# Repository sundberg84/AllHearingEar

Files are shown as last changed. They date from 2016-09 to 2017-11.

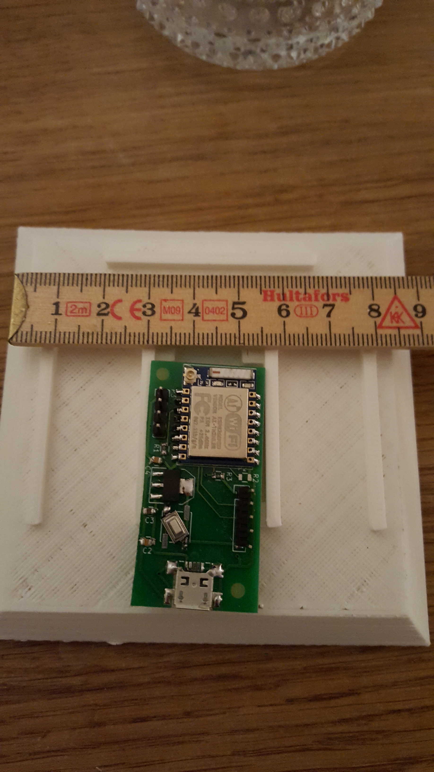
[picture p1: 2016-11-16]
hardware/3d model/Pyramid 0.2/20161116_210414.jpg

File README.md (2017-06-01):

# AllHearingEar
 
## Slogan (eng)
Open the world for your headphones!
Are you afraid of missing out on something with your headphones covering your ears? 

## Produktbeskrivning (eng)
We believe it’s possible to combine a world with your headphones covering your ears and still not miss anything important happening IRL. Are you a gamer with sleeping children or a reader listening to recorded books and are afraid of missing something is happening? We have the product for you - AllHearingEar! Just because you are covering your ears to fully enjoy your sound should not stop you from hearing a crying baby or a visitor ringing the doorbell. 

The AllHearingEar is always and secure connected to you home Wi-Fi and alerts you with the exact recording in real time. This way you can enjoy your gaming, videos, music or voice with headphones in both ears and still safely know you will be alerted if needed.

The AllHearingEar is a onetime, low-cost hardware you connect to your home Wi-Fi. Free apps and software are downloaded and run in the background of your PC, smartphone or tablet. The software and hardware have a live status and will alert you if disconnected. You have the endless possibility to adjust trigger limits from even the smallest sound to a small orchestra.

All this to be able to enjoy your gaming in full 7.1 sound or a quiet book tucked inside a blanket by the fire - and always know you are in control.

## Idé:
Skapa en babymonitor som ansluter till hemmanätverket via WI-FI och bryter aktivt ljud i din hemdator samt spelar upp ljudet som tas upp av mikrofonen i babymonitorn. 
Detta för att kunna underlätta för användaren av datorn när användaren spelar spel, ser film, lyssnar på musik eller liknande.
Idén uppkom när jag och min bror spelade datorspel tillsammans och båda två var tvungna att sitta med endast en hörlur på ena örat.
Vi vill alltså ha möjlighet att höra våra barn om de eventuellt vaknar, utan att tappa ljud när vi arbetar med våra datorer.

##Namn
Om vi nu ska köra på illuminati pyramid kan vi istället för att produkten heter all-seeing-eye heta all-hearing-ear ?

### Utförande
USB-stick
Pyramid

## Ström?

USB Anslutningar - Konsument står för egna adapters.
Anslutes till telefonladdare - standard USB / MicroUSB.

## Hårdvara

Andreas bygger hårdvara i form av kretskort och mikrofoner. Samt designar ett snyggt och praktiskt hölje!

- Esp8266 Wifi Accesspoint/Server (https://github.com/tzapu/WiFiManager )
- 5V VCC (iphone laddare?) Batteri?
- 3.3V för Esp?
- Electret Microphone Amplifier MAX4466
- Statusled?
- Nattlampa LED

"" PreAmplifier
- OPA3344
https://learn.sparkfun.com/tutorials/electret-mic-breakout-board-hookup-guide
http://www.ti.com/lit/ds/symlink/opa345.pdf

Avoid common problems when designing op-amp and in-amp circuits:
http://www.planetanalog.com/document.asp?doc_id=527560

Div PreAmp
https://arduinodiy.wordpress.com/category/audio/

Noice reduction

General power supply and op-amp noise reduction techniques
http://www.diystompboxes.com/smfforum/index.php?topic=74265.0

Basic Concepts of Designing an RF PCB Board:
https://www.eeweb.com/blog/circuit_projects/basic-concepts-of-designing-an-rf-pcb-board

Small- Signal Audio Design (s.541)
https://books.google.se/books?id=pVIdAAAAQBAJ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

http://www.ti.com/lit/an/szza009/szza009.pdf

https://www.maximintegrated.com/en/app-notes/index.mvp/id/5450

## Skal 
3d pyramid
- 3d printad iluminati pyramid (http://www.shapeways.com/product/G3PZPGYJB/illuminati-flat-peice-v2e)
-Hål undertill för väggfäste!

USB sticka:
- https://stickerapp.se/klistermarken/#!
- http://www.mouser.se/ProductDetail/New-Age-Enclosures/P3A-220805S/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

## Länkar Hårdvara

Microfoner: https://store.invensense.com/ProductDetail/ICS43432-InvenSense-Inc/495200/

https://www.hackster.io/middleca/sending-sound-over-the-internet-f097b4

Https://plus.google.com/wm/1/+MarkChaney/posts/EpTNcAjxMak

https://perso.aquilenet.fr/~sven337/english/2016/07/14/DIY-wifi-baby-monitor.html

#### Ljud/Mic till Arduino:

Https://perso.aquilenet.fr/~sven337/english/2016/07/14/DIY-wifi-baby-monitor.html

https://electronpi.wordpress.com/2013/05/28/getting-going-with-an-electret-microphone-and-an-arduino/
Inkl flera länkar på denna sida!

https://www.youtube.com/watch?v=SToBPCajwc0: Mini project: Amplified electret microphone 

Sök arduino electret microphone circuit

## Wishlist
Kamera

## Mjukvara

Marcus utformar en mjukvara till Windows som synkar hårdvaran och bryter eventuellt ljud som spelas upp från datorn. För att sedan spela upp ljudet från monitorn.
Synkning av hårdvara,
 
Volymkontroll för uppspelning av ljud upptaget av mikrofon, 

Volymkontroll för dämpning av ljud aktiva i PC,
 
Volymkontroll för känslighet i mikrofon,
 
Alternativ för autostart av program (Checkbox),
 
Statusinformation, 

Länk till hemsida.

### Länkar till källor.

https://www.nuget.org/packages/NAudio/1.7.3 (NAudio API för inspelning av ljud i VB)

https://social.msdn.microsoft.com/Forums/vstudio/en-US/c9841350-2d83-4863-b491-6d9f75bb1daa/stream-mic-audio-to-another-computer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 (Exempelprogramm för ljudstream via UDP.)

http://www.codeproject.com/Articles/19485/A-Voice-Chat-Application-in-C - A Voice Chat Application in C#

### Wishlist
Knapp för att visa video.
Alternativ för att få video picture in picture när monitor aktiveras.

##Det kommerciella
###Ce/Fee
###Strömadapter
###Förpackning
###Ekonomi
Kickstarter?
###Marknadsföring
Hemsida
Facebook
###Målgrupp
Gamers
Unga med barn
Teknikintresserade (hörlurar) (Sälja hörlurar tillsammans?)
###Användningsområde

Gamers som passar barnen men vill spela
Mammor som lyssnar på ljudböcker? (Kräver app ios/Android?)
Egenföretagare med barn som behöver jobba kväll och vill lyssna på musik.
Studerande med barn som jobbar med datorn och lyssnar på musik.
Musiker som jobbar hemma.
Arbetande tjänstemän som behöver använda en dator i jobbet medans barnen sover.

##Produktbeskrivning/Anvädningsområde
Vi vill alltså ha möjlighet att höra våra barn om de eventuellt vaknar, utan att tappa ljud när vi arbetar med våra datorer.
På ett smart sätt höra din omgivning, exempelvis barn som vaknar, utan att tappa ljud via hörlurarna när man arbetar vid dator/platta/mobil.

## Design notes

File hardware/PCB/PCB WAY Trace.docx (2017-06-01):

PCB WAY 50ohm trace widht

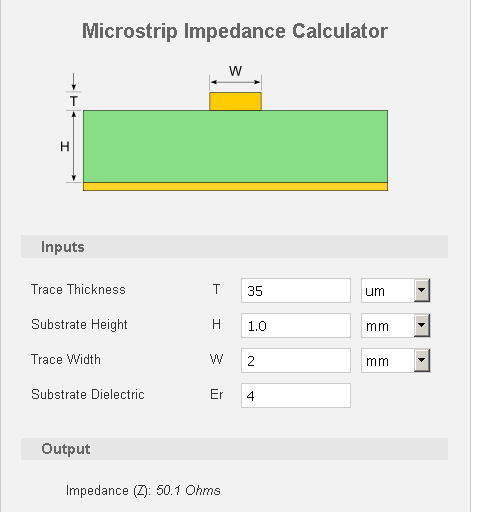
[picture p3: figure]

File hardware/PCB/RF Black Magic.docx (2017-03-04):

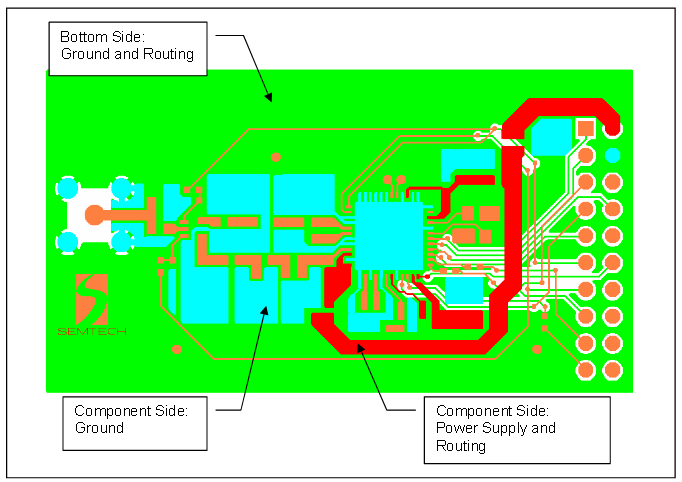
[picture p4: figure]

- power supply trace on the component I s made quite thick so as to present as low as impedance trace as possible.
- Large areas of ground on this side of the board provide a low impedance path for decoupling.
- Wherever possible the bottom (copper) side of the board should allow for a solid ground plane under the RF circuitry.
- the PCB thickness should not exceed 0.8mm - 1.00mm
- Minimize current loops on PCB layouts by decoupling as close to the port being decoupled to ground as possible.
- each circuit block or port has its own decoupling capacitor.
- Ensure that each decoupling capacitor has its own via connection to ground. As a rule of thumb, components should not share vias.

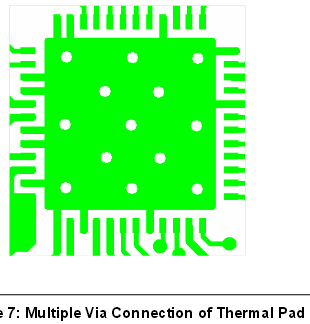
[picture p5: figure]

- Figure 7 illustrates the multiple via (or “well stitched”) connection of the thermal relief pad to the main (inner) ground layer.
- RF Transmission Lines: Lines should be kept as far apart as possible, and should not be routed in close proximity for extended distances.
- High-Speed Digital Signal Lines: These lines should be routed separately on a different layer than the RF signal lines, to prevent coupling. Digital noise (from clocks, PLLs, etc.) can couple onto RF signal lines, and these can be modulated onto RF carriers. Alternatively, in some cases digital noise can be up/down-converted.
- VCC/Power Lines: These should be routed on a dedicated layer. Adequate decoupling/bypass capcitors should be provided at the main VCC distribution node, as well as at VCC branches. The choice of the bypass capacitances must be made based on the overall frequency response of the RF IC, and the expected frequency distribution nature of any digital noise from clocks and PLLs. These lines should also be separated from any RF lines that will transmit large amounts of RF power.
- two layer, the top layer should include the power stage, RF signal lines and RF components. Then the bottom layer must be the ground plane.
- Draw the RF signal lines quite separately. If they are adjacent to eachother, then crosstalk may occur. (Crosstalk : Undesired transfer of signals between or among two lines such as telephone lines, data lines, or system components. )
- When you finish all the layers, fill the empty spaces with copper pour that is connected to the ground. Place vias that are connected to the ground layer with a distance of λ/20 cm between eachother.

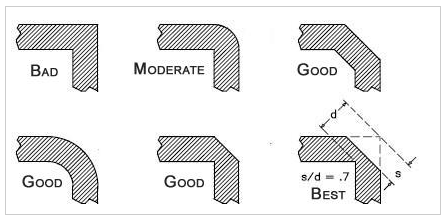
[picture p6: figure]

- Decouple the supply voltage. An example circuit and its PCB is shown below. Consider that the capacitor with a smaller capacitance is placed nearer to the IC.

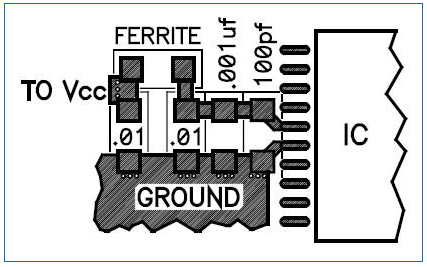
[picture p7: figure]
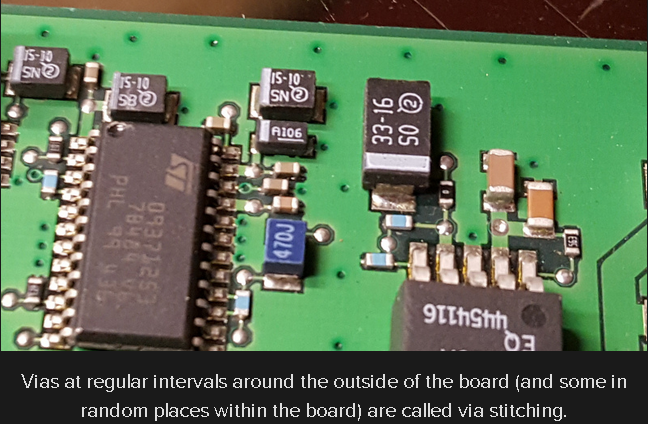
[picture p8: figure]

- trace that is near the edge of the board and farther from a ground plane layer will radiate more electromagnetic interference. Via stitching refers to putting a ring of vias attached to the ground plane all the way around the edge of the PCB (or as much as possible). n addition, a healthy dose of vias should connect the ground pour to the ground plane This prevents accidental antennas, and also ensures that the whole ground stays at the same potential all the time.
- The ferrite bead is usually used when connecting a switching power supply to the power plane, as it isolates the noise from the supply, so it is placed (along with a decoupling capacitor) next to the power supply output.
- Keep Traces Short - The crystal should be as close as possible to the microcontroller, with the wires going directly between the two. Every extra millimeter is more changing electric field and more emissions. A UART can have much longer wires because the signal doesn’t change as fast, and the positive voltage rails can meander all over.
- A two-layer board can achieve 95% of the effectiveness of a four-layer board by emulating what makes a four-layer board better:
  - Make an extra effort to route ground underneath power.
  - Grid power and ground, but be careful not to create unneeded common impedance connections or to violate an intended isolation, such as between high-power and digital grounds. See section 2.2.3, Gridding to Create Planes.
  - Route returns for direct connections to the processor I/Os directly under the signal trace. Gridding is aspace-effective way of doing this. See section 2.2.3, Gridding to Create Planes.
  - Under the microcomputer, build a solid plane for ground that bypassing components and the oscillator loop can be tied to. Tie this ground to the ground pin and the power-supply bypass capacitor. This is called a microcomputerground, which is discussed in section 2.1.3.
- 2.2.3 Gridding to Create Planes

Gridding is the most critical design technique for two-layer boards. Much like a power utility grid, gridding is a network of orthogonal connections between traces carrying ground. It effectively creates a ground plane, which provides the same noise reduction as on four-layer boards. It serves two purposes:

- Emulates the ground plane of a four-layer board by providing a ground return path under each of the signal traces
- Lowers the impedance between the microcomputer and the voltage regulation

Gridding is done by expanding any ground traces and using ground-fill patterns to create a network of connections to ground across the PCB. For example, a PCB has most of the topside traces running vertically and most of the bottom traces running horizontally (see Figure 7). This already is working against having the return run directly under signal. First, every ground trace is expanded to fill up as much of the empty PCB space as possible. Then, all the remaining empty space is filled with ground. Place through holes where top-side traces cross bottom-side traces. Then do the same to the ground-fill patterns. Ground-fill patterns make a better contribution to the grid if they are tied to ground at both ends. A ground-fill-pattern geometry connected at only one point is just a ground shield, but if connected at two or more points, it becomes a conductor, and, therefore, becomes a contributor in the grid.

- Grid as much as possible on a two-layer board. Look for places where small changes in the layout would allow another connection to be made in the grid.
- Use as many through holes as can physically fit.
- Lines do not have to be orthogonal, or of the same width.

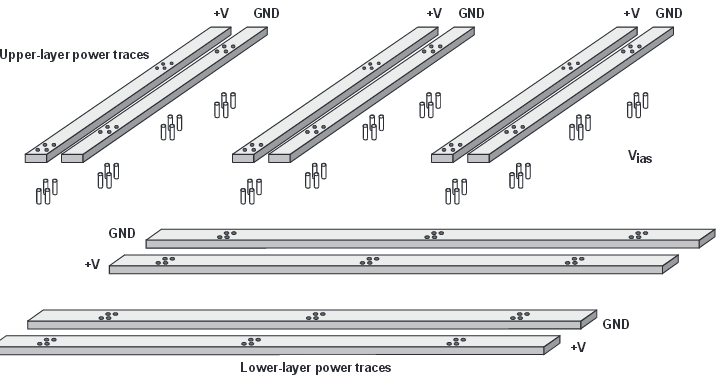
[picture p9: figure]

8

An example of gridding ground only to achieve the effect of a ground plane is shown in Figure 8. Note how the changes made

in order to implement this were minor, indicating how a small effort can have a large payback.

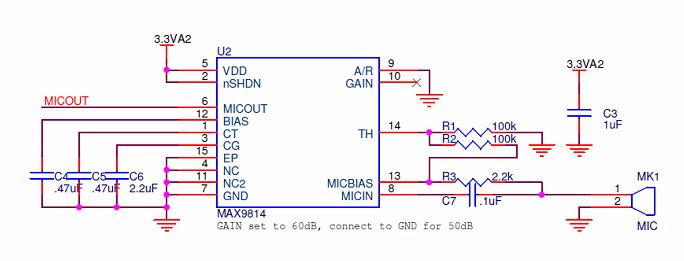
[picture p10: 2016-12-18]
hardware/PCB/UsbSticka/Res/Max9814.JPG

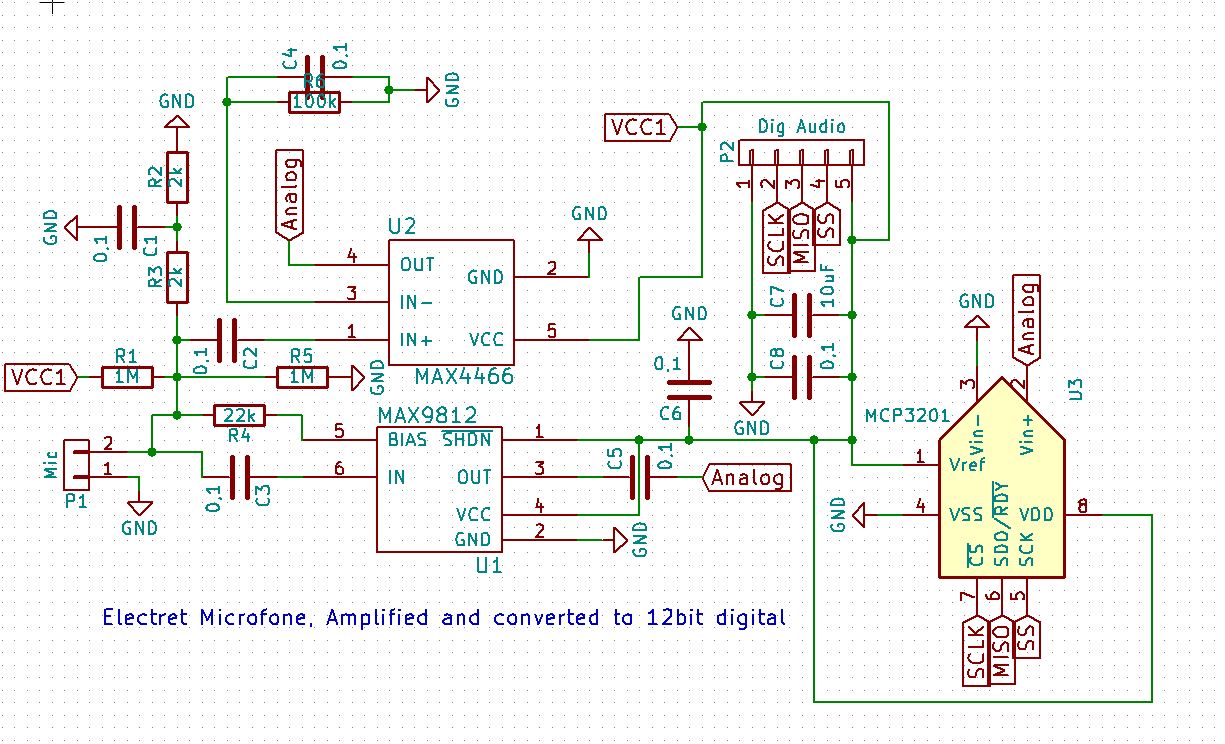
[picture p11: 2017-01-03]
hardware/PCB/UsbSticka/Res/Max4466.JPG

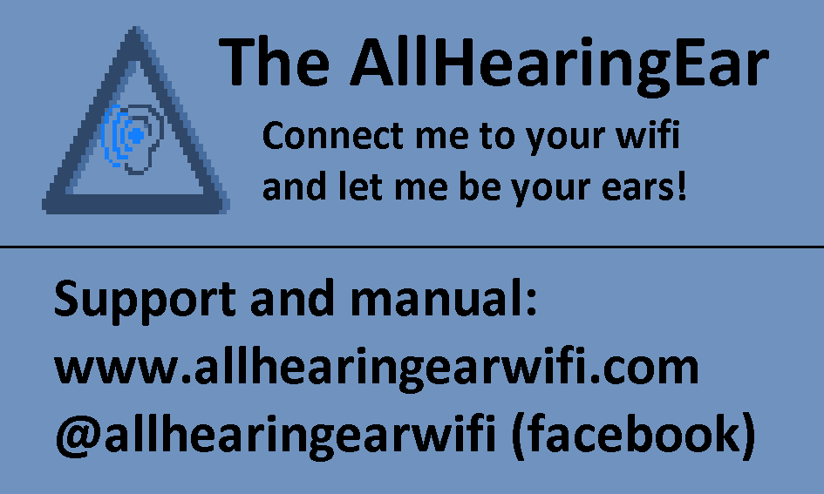
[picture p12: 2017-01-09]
hardware/3d model/sticker.png

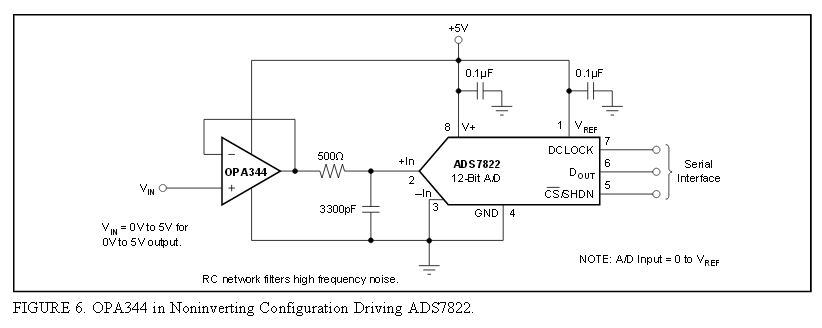
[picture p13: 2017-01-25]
hardware/PCB/UsbSticka/Res/OPA345pADC.JPG

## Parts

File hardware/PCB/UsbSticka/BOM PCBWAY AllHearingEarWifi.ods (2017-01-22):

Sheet: 1
No. | part number/description | Package | Value | Qty | RefDefs | Note
1 | USB Connector |  |  | 1 | P1
2 | LM1117-3.3 | SOT-223 |  | 1 | U1
3 | Capacitors | SMD 0805 | 0.1UF | 6 | C1.C2.C3.C5.C8.C9
4 | Capacitors | SMD 0805 | 10uF | 1 | C4
5 | Resistors | SMD 0805 | 10k | 1
6 | Resistors | SMD 0805 | 2.2k | 2 | R1, R2
7 | Resistors | SMD 0805 |  | 3 | R4.R5.R6
8 | Push Button | SMD |  | 1 | SW1 ??
9 | FERRITE,Capacitors | SMD:C_0805 |  | 1 | FB1
10 | MAX9813 5v | SOT-23-8 |  | 1 | u2
11

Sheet: Sheet1
U2 MT9V022I77ATM_ES@IBGA-52
U1 EMP7032SLC44-15@TQFP12FL12-44
J2 HEADER_13X2@CON26
J1 DOWNCABLE@CON10
X1 OSC@KDS-OSC-2025
C2 CAP_NP@CAP0402
C3 CAP_NP@CAP0402
C8 CAP_NP@CAP0402
C5 CAP_NP@CAP0402
C6 CAP_NP@CAP0402
C7 CAP_NP@CAP0402
C10 CAP_NP@CAP0402
C9 CAP_NP@CAP0402
C11 CAPACITOR_POL@SMC3528
C12 CAPACITOR_POL@SMC3528
L3 INDUCTOR@SMC0603
L2 INDUCTOR@SMC0603
C1 CAP_NP@CAP0402
L1 INDUCTOR@SMC0603
C4 CAP_NP@CAP0402
U3 COMPONENT_1@SOT23-5
C15 1-CAP-POL-MY@SMC3528
C16 1-CAP-POL-MY@SMC3528
R1 R@RES0402
R2 R@RES0402
C13 CAPACITOR_POL@SMC3528
U4 COMPONENT_1@SOT23-5
C19 1-CAP-POL-MY@SMC3528
C20 1-CAP-POL-MY@SMC3528
C14 CAP_NP@CAP0402
C17 CAP_NP@CAP0402
C22 CAP_NP@CAP0402
C18 CAP_NP@CAP0402
C21 CAP_NP@CAP0402
C23 CAP_NP@CAP0402
R3 R@RES0402
R4 R@RES0402

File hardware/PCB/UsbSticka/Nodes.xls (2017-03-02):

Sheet: Overview
ID | Rev | Name | Children | Location | Rep. | Parent | Power | Mys Ver. | Notes
0 | 1.0 | Gateway | Gateway | Hobby | X |  | 5v | 2.0.1b
1 | 1.2 | Hobbyrum | Temp/Hum | Hobby |  |  | Bat | 1.4.1
2 | 1.0 | Stora sovr. | Temp/Hum | Stora sovr. |  |  | Bat | 1.4.1
3 | 1.0 | Vardagsrummet | Temp | Vardagsrum |  |  | Bat | 1.4.1
4 | 1.0 | Radiotestaren | Timeaware | X |  |  | Bat
5 | 1.3? | Utomhus ? | Temp/Hum/Lux/baro | Vedboden | ? | ?/99 | 5V | ?
6
7 | 1.2 | Regn | Rain | Tak garage |  |  | Bat | 2.0b
8 | 1.3 | Elförbrukning | KWH | Proppskåp ute |  |  | Bat | 2.1.0r
9 | 1.2 | Gillestuga temp | Temp | Gillestuga |  |  | Bat | ?
10 | 1.2 | Motion Garage | Motion | Garaget |  | 99 | 5v | 2.0b | Inkl detection led
11 | 1.0 | Motion Vardagsrum | Motion | Vardagsrum |  |  | 5v | ?
12 | 1.3 | Paddington | Motion/Dist | Förräd/Gräskl. |  |  | 5v | 2.0.1b
13 | 1.0 | Utomhus Syd ? | Temp/Hum/Lux | Uterummet |  |  | AC to 5v | 2.0b
14 | 1.0 | UtomhusHumNorr | Temp/Hum | Under trappan |  |  | Bat | 2.0b
15 | 1.0 | UtomhusHumSyd | Temp/Hum | Tak uterum |  |  | Bat | 2.0b
16 | 1.1 | Dec Köket #16 | Motion | Köket |  |  | Bat | 2.1.0r | Slim node 1mhz, APM Optiboot internal 1MHz noBOD 9600baud
17 | 1.0 | Temp Vinden | Temp/hum | Vinden |  |  | Bat | 2.0b
18
19 | 1.2 | UV | UV/Lux | Tak uterum |  |  | Bat | 2.0b
20
99 | 1.2 | WW Sov | Motion | Sov WW | X |  | 5v | 2.1 | Repeater!
100 | 1.6 | Hallen | Repeater | Hallen | X |  | 5v | 2.0.1b | Repeater!
105 | 1.1 | LCD | Switch x 5 (lcd) | Köket | X |  | AC to 5v | 1.6.0b | Down!
106
RFLINK 433mhz
0113C882 |  | 1 | Fönsterlampor Sov
0113C882 |  | 2 | Fönsterlampa WW Sov
0113C882 |  | 3 | Fönsterlampa Malwa Sov
10;NewKaku;1040404;1;OFF |  |  | Taklampa Köket

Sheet: Rev history
ID | Rev | Ver
0 | 1.0
1 | 1.2
2 | 1.0
3 | 1.0
4 | 1.0
5 | 1.0-1.2 |  | Sketch
 | 1.3 |  | Forecast algorithm
 | 1.4 |  | 99 as repeter, 5min sleep eller process hela tiden utan sleep - skicka endast ibland.
6
7 | 1.0 |  | Regn bucket
 | 1.1 | 1.6.0b | Parent=Auto
 | 1.2 | 2.0.0b | Parent Auto, sendHeartbeat()
8 | 1.0 |  | KWH (räknar pulser)
 | 1.1 |  | Bat övervakning + sleep mode igångsatt,
 | 1.2 |  | loop tills count recieved, rensad kod och lagt till ext resistor för debounce.
 | 1.3 | 1.6.0b | Skicka varje 250 pulser
 | 1.4 | 2.1.0r | 2xAA batteri, Sleep time x 5 för rätt sekunders sleep (nu 15 min) (Feb-17)
9 | 1.2
10 | 1.0 |  | Motion med LED på pin 4
 | 1.1 |  | 2.0beta, sänder både 1+0, glömt LED
 | 1.2 | 2.0.0b | LED tillagt igen
11 | 1.0 |  | Motion
12 | 1.0 |  | Motion/Distance
 | 1.1 |  | Tog bort sleep och la till sendHeartBeat() varje timme
 | 1.2 |  | Sänd inga 0 värde (kan ej läsa distance) - fel, ej implement
 | 1.3 | 2.0.1b | Return om distance = 0 för att undvika sändning av falska/error värde (0), ej fixed parent. (Sept 16)
13 | 1.0 |  | Temp/Hum/Lux
14 | 1.0 |  | Temp/Hum
 | 1.1 | 2.1
15 | 1.0 |  | Temp/Hum
16 | 1.0 | 2.0.0b | Motion, 5v motion (9v bat) ingen batövervakning.
 | 1.1 | 2.0.1b | SLim node, 9v to 3.3 via le33az
 | 1.2 | 2.1.0r | Slim node 3.3v 1mhz Optiboot Nu I köket (Feb-17)
17 | 1.0
18
19 | 1.0 | 2.0.0b | UV/Light
 | 1.2 | 2.0.0b | För hög sleep konsumtion, sensors på IO med HIGH/LOW istället.
 | 1.3 | 2.0.1b | BatM() fungerar inte, la till analogReference(INTERNAL); som saknades i setup()
20
21
22
23
24
25
99 | 1.2 | 2.0.1b | Version upgrade, metall folierat case (Sept 16)
 |  | 2.1 | Ny strömadapter, uppdaterad till 2.1
100 | 1.4
 | 1.5 | 2.0.0b | Upgraderar till 1.6.0b, lägger till sänder både 1+0
 | 1.6 | 2.0.1b | Uppgraderar till 2.0.1b, metall case (sept 16)
102 | 1.0 |  | DOWN
103 | 1.0
104 | 1.0
105 | 1.1
106

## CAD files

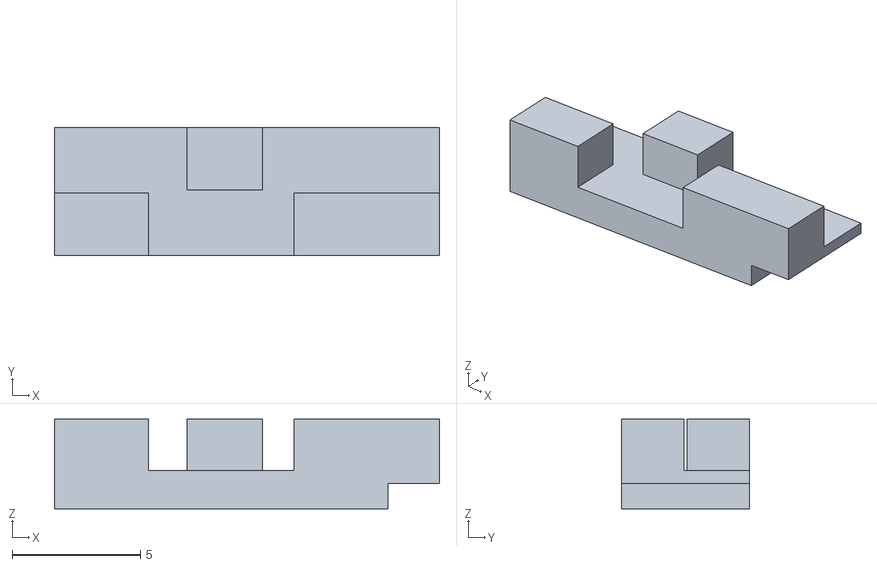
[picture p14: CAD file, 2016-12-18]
hardware/3d model/Bandlås/bandlås-013Bsträng.stl
15.0 x 5.00 x 3.50

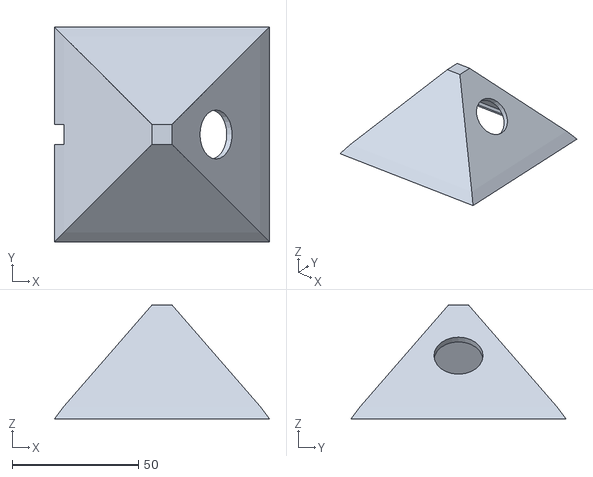
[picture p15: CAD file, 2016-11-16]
hardware/3d model/Pyramid 0.2/Topp02rep.stl
85.0 x 85.0 x 45.0

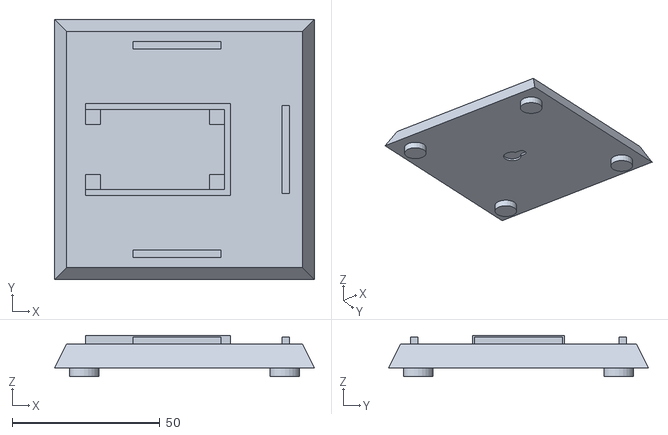
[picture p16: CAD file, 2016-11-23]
hardware/3d model/Pyramid 0.4/PyramidBr.stl
88.0 x 88.0 x 14.0

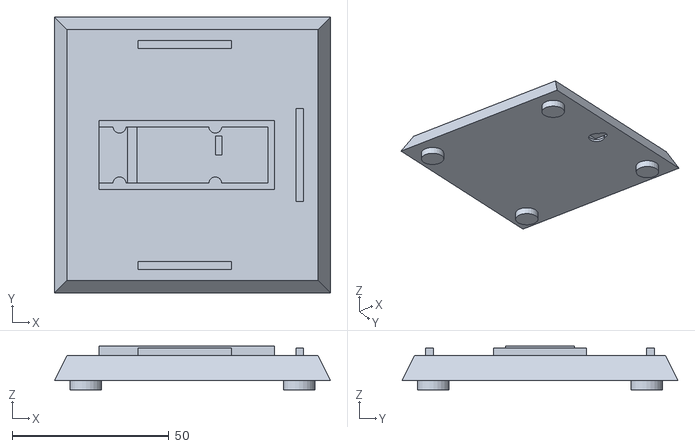
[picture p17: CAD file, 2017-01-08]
hardware/3d model/Pyramid 0.5/BOTT06BUILD.stl
88.0 x 88.0 x 14.0

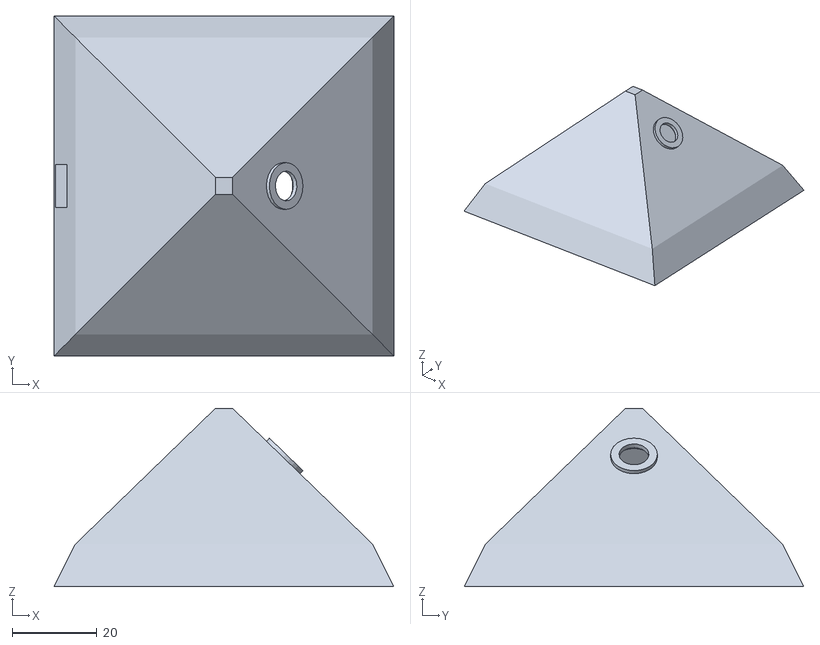
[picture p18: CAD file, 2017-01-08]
hardware/3d model/Pyramid 0.6/TOP06BUILDrep.stl
80.0 x 80.0 x 42.0

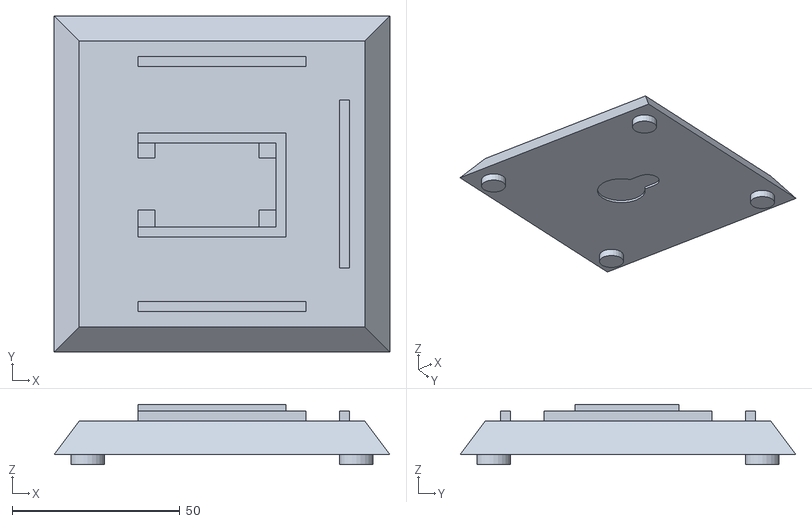
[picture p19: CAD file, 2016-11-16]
hardware/3d model/Pyramid 0.2/Botten02.stl
100.0 x 100.0 x 18.0

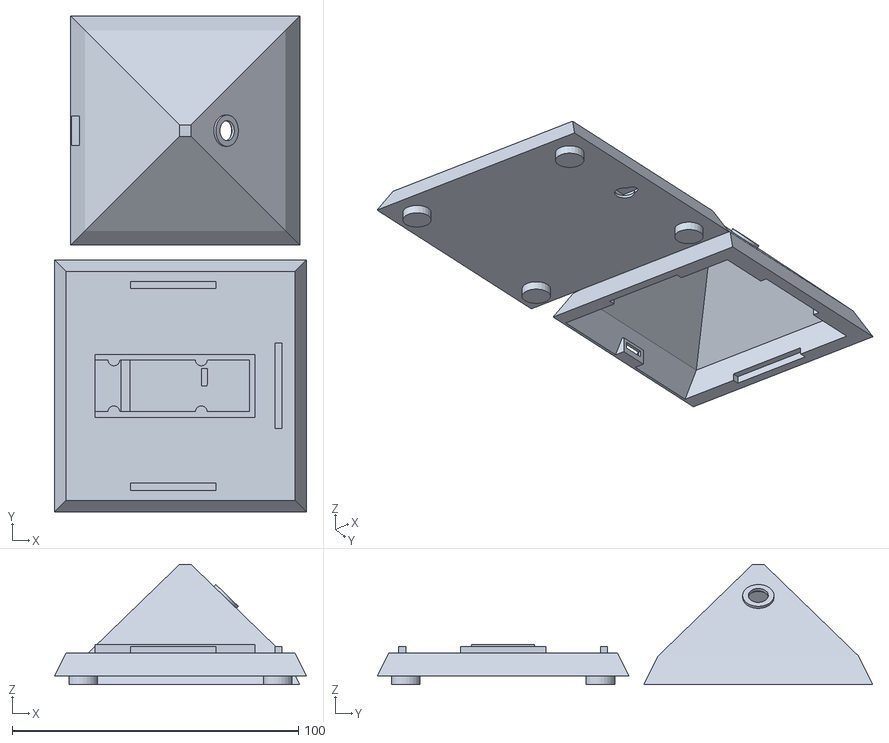
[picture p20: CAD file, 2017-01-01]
hardware/3d model/Pyramid 0.5/Pyramid 0.6BUILDrep.stl
88.0 x 173.1 x 42.0

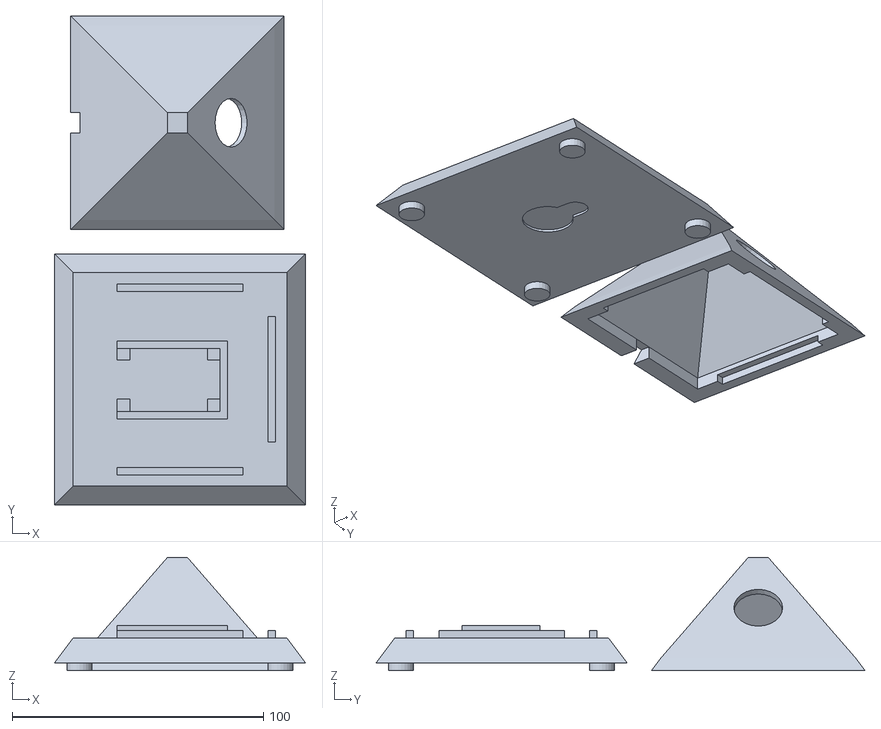
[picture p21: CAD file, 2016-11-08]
hardware/3d model/Pyramid 0.2/Pyramid02.stl
100.0 x 194.7 x 45.0

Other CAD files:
hardware/3d model/Bandlås/bandlås-013Bsträng-rep.stl
hardware/3d model/Pyramid 0.2/Topp02.stl
hardware/3d model/Pyramid 0.4/PyramidTr.stl
hardware/3d model/Pyramid 0.5/TOP06BUILD.stl
hardware/3d model/Pyramid 0.6/newTOP06BUILDrep.stl
hardware/3d model/Pyramid 0.4/PyramidB.stl
hardware/3d model/Pyramid 0.6/BOTT06BUILDrep.stl
hardware/3d model/Pyramid 0.2/Botten02Rep.stl
hardware/3d model/Pyramid 0.4/PyramidT.stl
hardware/3d model/Pyramid 0.5/Pyramid 0.6BUILD.stl
hardware/3d model/Bandlås/bandlås.skp
hardware/3d model/Pyramid 0.1/Pyramid.skp
hardware/3d model/Pyramid 0.1/kretskort.skp
hardware/3d model/Pyramid 0.2/Botten02.skp
hardware/3d model/Pyramid 0.2/Pyramid02.skp
hardware/3d model/Pyramid 0.2/Pyramid02rep.stl
hardware/3d model/Pyramid 0.2/Topp02.skp
hardware/3d model/Pyramid 0.3/Pyramid03.skp
hardware/3d model/Pyramid 0.4/Pyramid 0.4.1.skp
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

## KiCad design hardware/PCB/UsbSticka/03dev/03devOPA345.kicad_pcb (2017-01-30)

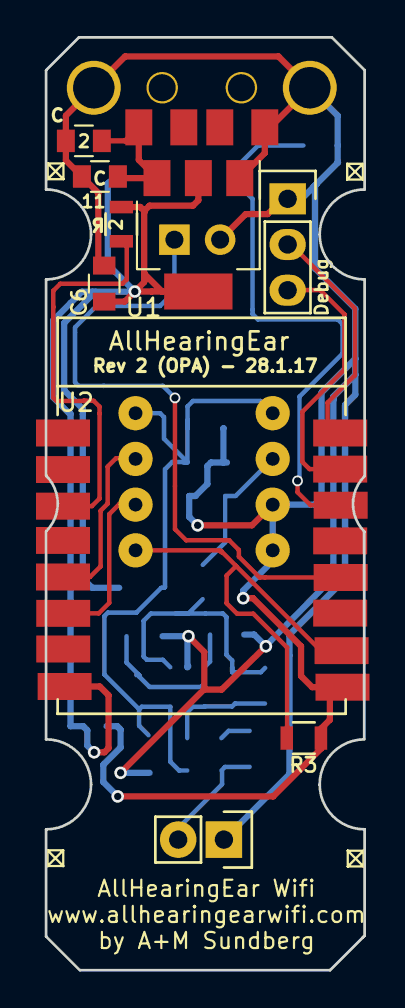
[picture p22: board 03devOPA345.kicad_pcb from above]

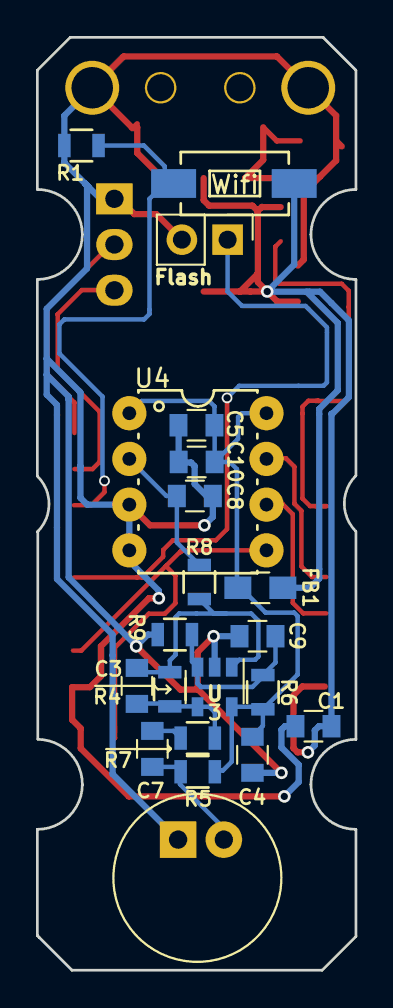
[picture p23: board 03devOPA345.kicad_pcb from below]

Board: 2 copper layers, 17.7 x 51.8 mm, 28 parts (19 on the bottom side), 17 nets.

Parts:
2: 10uF; C_0805
2#2: 10k; R_0805
3: OPA345; SOT-23-5
11: 0,1uF; C_0805
C1, C6: 0,1uF; C_0805
C3, C4, C5, C10: 0,1; C_0805
C7, C9: 4,7; C_0805
C8: 3300pF; C_0805
Debug: Debug; Socket_Strip_Straight_1x03
FB1: FERRITE; C_0805_HandSoldering
P1: USB_B; USB_A_AS_PADS
R1, R3, R6, R7, R9: 10k; R_0805
R4: 820k; R_0805
R5: 2,2k; R_0805
R8: 500; R_0805
U1: LM1117-3.3; SOT-223
U2: ESP-07v2; ESP-07_AS
U4: MCP3201; PDIP-8
Wifi: SW_PUSH; SW_SPST_EVQPE1

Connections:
+5V: 2.1, 11.1, P1.1, U1.3
GND: 2.2, 3.2, 11.2, C1.2, C4.2, C5.1, C6.2, C8.2, C9.1, C10.1, Debug.1, P1.4, P1.5, R1.1, R3.2, R9.2, U1.1, U2.9, U4.3, U4.4
MISO: U2.6, U4.6
unnamed: 3.1, C3.1, R4.1, R8.2
unnamed: 3.4, C3.2, R4.2, R7.1
unnamed: C7.1, R5.1
unnamed: C7.2, R7.2
unnamed: C8.1, R8.1, U4.2
unnamed: 3.3, C9.2, R6.2, R9.1
unnamed: 3.5, C4.1, C5.2, C10.2, FB1.1, R5.2, R6.1, U4.1, U4.8
unnamed: Debug.2, U2.16
unnamed: Debug.3, U2.15
unnamed: R1.2, U2.14, Wifi.1
unnamed: 2#2.1, U2.3
SCLK: U2.5, U4.7
SS: R3.1, U2.10, U4.5
VCC: 2#2.2, C1.1, C6.1, FB1.2, U1.2, U1.4, U2.8, Wifi.2

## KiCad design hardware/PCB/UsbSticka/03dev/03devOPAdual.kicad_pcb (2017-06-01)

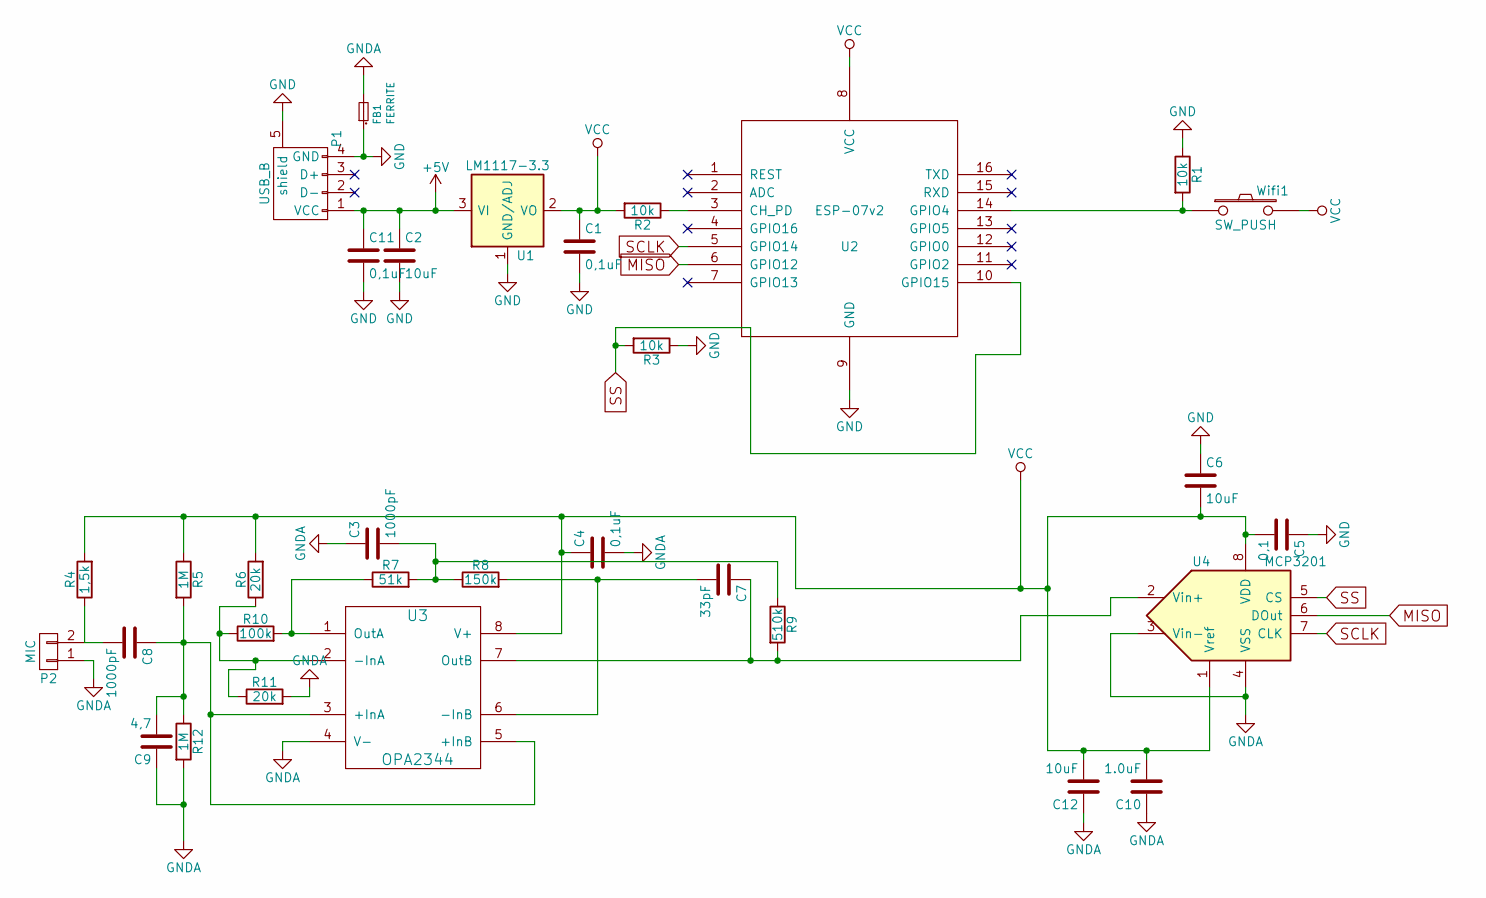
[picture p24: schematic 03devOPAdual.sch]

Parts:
C1, C4, C11: 0,1uF; C_0805_HandSoldering
C2, C6, C12: 10uF; C_0805_HandSoldering
C3, C8: 1000pF; C_0805_HandSoldering
C5: 0,1; C_0805_HandSoldering
C7: 33pF; C_0805_HandSoldering
C9: 4,7; C_0805_HandSoldering
C10: 1.0uF; C_0805_HandSoldering
FB1: FERRITE; C_0805_HandSoldering
P1: USB_B; USB_A_AS
P2: MIC; Socket_Strip_Straight_1x02_Pitch2.54mm
R1, R2, R3: 10k; R_0805_HandSoldering
R4: 1,5k; R_0805_HandSoldering
R5, R12: 1M; R_0805_HandSoldering
R6, R11: 20k; R_0805_HandSoldering
R7: 51k; R_0805_HandSoldering
R8: 150k; R_0805_HandSoldering
R9: 510k; R_0805_HandSoldering
R10: 100k; R_0805_HandSoldering
U1: LM1117-3.3; SOT-223
U2: ESP-07v2; ESP-07_AS
U3: OPA2344; SOIC-8_3.9x4.9mm_Pitch1.27mm
U4: MCP3201; SOIC-8_3.9x4.9mm_Pitch1.27mm
Wifi1: SW_PUSH; SW_PUSH_AS

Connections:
+5V: C2.1, C11.1, P1.1 (VCC), U1.3 (VI)
GND: C1.2, C2.2, C5.1, C6.1, C11.2, FB1.1, P1.4 (GND), P1.5 (shield), R1.1, R3.1, U1.1 (GND/ADJ), U2.9 (GND)
GNDA: C3.1, C4.2, C9.1, C10.1, C12.1, FB1.2, P2.1, R11.2, R12.2, U3.4 (V-), U4.3 (Vin-), U4.4 (VSS)
MISO: U2.6 (GPIO12), U4.6 (DOut)
unnamed: C3.2, R7.2, R8.1, R9.1
unnamed: C7.1, R9.2, U3.7 (OutB), U4.2 (Vin+)
unnamed: C7.2, R8.2, U3.6 (-InB)
unnamed: C8.1, C9.2, R5.2, R12.1, U3.3 (+InA), U3.5 (+InB)
unnamed: C8.2, P2.2, R4.1
unnamed: R1.2, U2.14 (GPIO4), Wifi1.1
unnamed: R2.1, U2.3 (CH_PD)
unnamed: R6.1, R10.1, R11.1, U3.2 (-InA)
unnamed: R7.1, R10.2, U3.1 (OutA)
SCLK: U2.5 (GPIO14), U4.7 (CLK)
SS: R3.2, U2.10 (GPIO15), U4.5 (CS)
VCC: C1.1, C4.1, C5.2, C6.2, C10.2, C12.2, R2.2, R4.2, R5.1, R6.2, U1.2 (VO), U1.4 (VO), U2.8 (VCC), U3.8 (V+), U4.1 (Vref), U4.8 (VDD), Wifi1.2

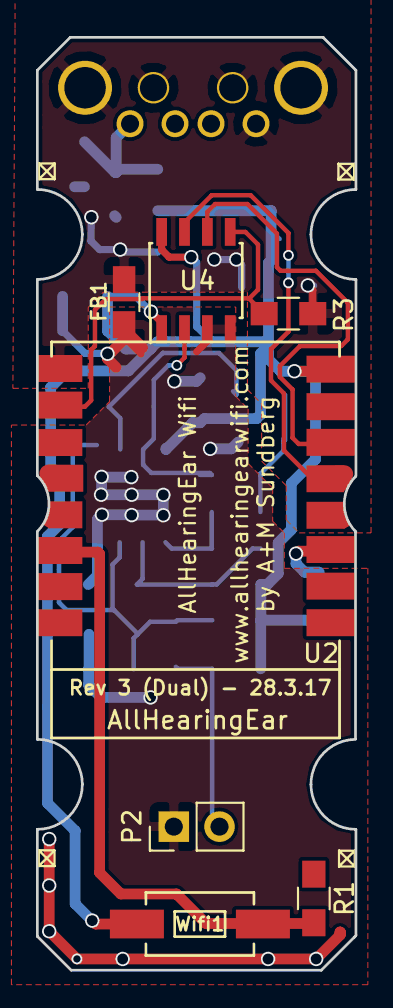
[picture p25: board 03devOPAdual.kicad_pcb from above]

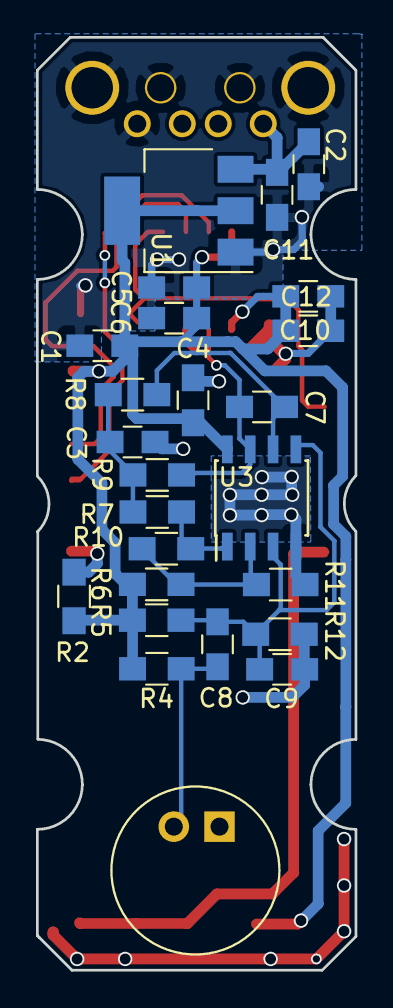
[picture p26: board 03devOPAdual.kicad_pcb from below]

Board: 2 copper layers, 17.7 x 51.8 mm, 32 parts (24 on the bottom side), 16 nets.

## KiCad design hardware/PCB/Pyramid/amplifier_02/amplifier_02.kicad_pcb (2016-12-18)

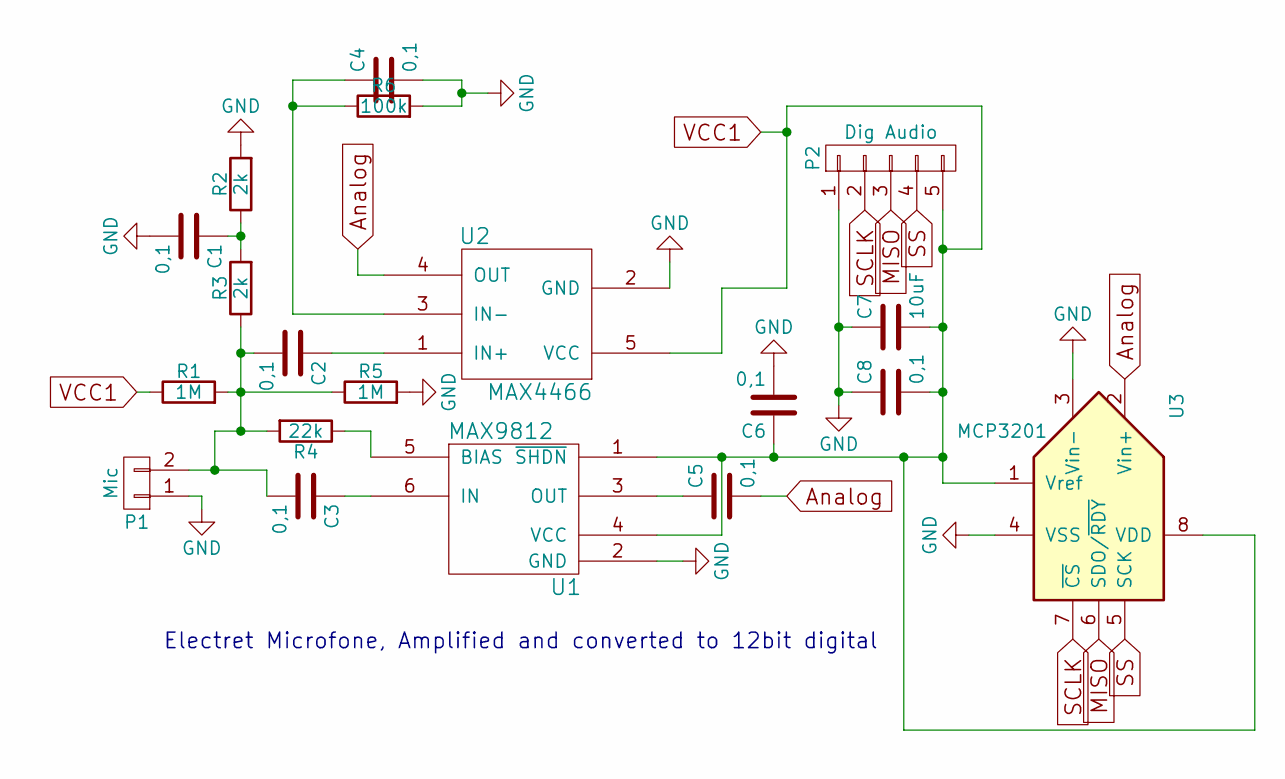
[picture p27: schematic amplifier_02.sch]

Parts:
C1, C2, C3, C4, C5, C6, C8: 0,1; C_0805
C7: 10uF; C_0805
P1: Mic; Pin_Header_Straight_1x02
P2: Dig Audio; Pin_Header_Straight_1x05
R1, R5: 1M; R_0805
R2, R3: 2k; R_0805
R4: 22k; R_0805
R6: 100k; R_0805
U1: MAX9812; SC-70-6
U2: MAX4466; SC-70-5
U3: MCP3201; PDIP-8

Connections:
Analog: C5.2, U2.4 (OUT), U3.2 (Vin+)
GND: C1.2, C4.2, C6.2, C7.1, C8.1, P1.1, P2.1, R2.2, R5.2, R6.2, U1.2 (GND), U2.2 (GND), U3.3 (Vin-), U3.4 (VSS)
MISO: P2.3, U3.6 (SDO/~RDY~)
unnamed: C1.1, R2.1, R3.2
unnamed: C2.1, U2.1 (IN+)
unnamed: C2.2, C3.2, P1.2, R1.2, R3.1, R4.2, R5.1
unnamed: C3.1, U1.6 (IN)
unnamed: C4.1, R6.1, U2.3 (IN-)
unnamed: C5.1, U1.3 (OUT)
unnamed: R4.1, U1.5 (BIAS)
SCLK: P2.2, U3.7 (~CS~)
SS: P2.4, U3.5 (SCK)
VCC1: C6.1, C7.2, C8.2, P2.5, R1.1, U1.1 (~SHDN), U1.4 (VCC), U2.5 (VCC), U3.1 (Vref), U3.8 (VDD)

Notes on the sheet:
Electret Microfone, Amplified and converted to 12bit digital

Board: 2 copper layers, 19 parts (0 on the bottom side), 13 nets, no tracks yet.

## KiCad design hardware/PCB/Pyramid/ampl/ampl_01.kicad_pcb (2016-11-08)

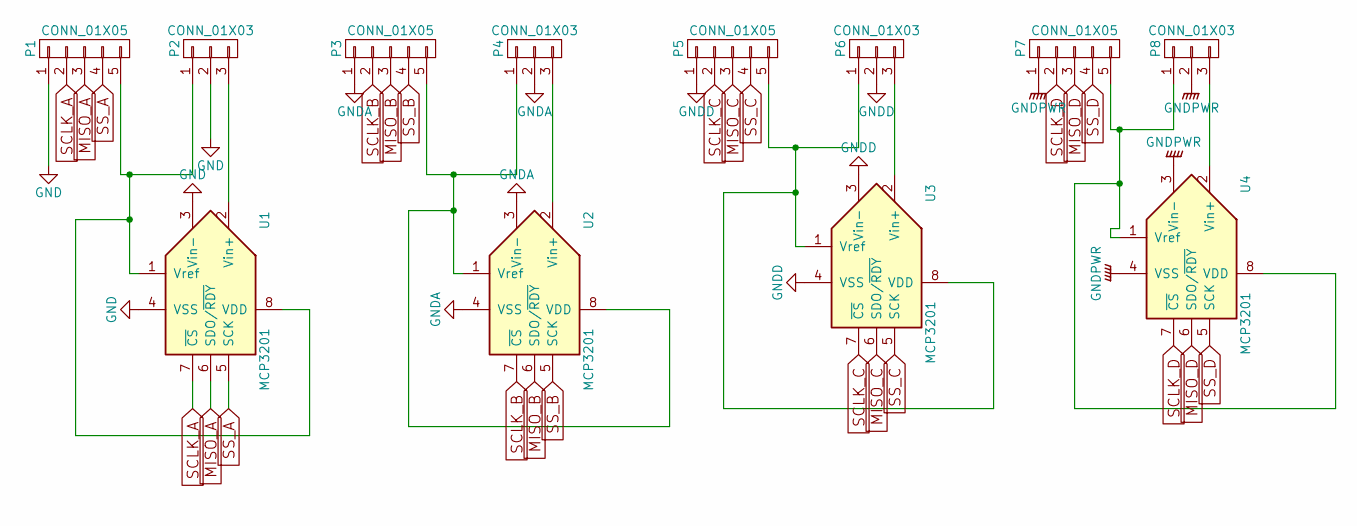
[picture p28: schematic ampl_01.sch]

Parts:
P1, P3, P5, P7: CONN_01X05; Pin_Header_Straight_1x05
P2, P4, P6, P8: CONN_01X03; Pin_Header_Straight_1x03
U1, U2: MCP3201; SOIC-8_3.9x4.9mm_Pitch1.27mm
U3, U4: MCP3201; PDIP-8

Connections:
GND: P1.1, P2.2, U1.3 (Vin-), U1.4 (VSS)
GNDA: P3.1, P4.2, U2.3 (Vin-), U2.4 (VSS)
GNDD: P5.1, P6.2, U3.3 (Vin-), U3.4 (VSS)
GNDPWR: P7.1, P8.2, U4.3 (Vin-), U4.4 (VSS)
MISO_A: P1.3, U1.6 (SDO/~RDY~)
MISO_B: P3.3, U2.6 (SDO/~RDY~)
MISO_C: P5.3, U3.6 (SDO/~RDY~)
MISO_D: P7.3, U4.6 (SDO/~RDY~)
unnamed: P1.5, P2.1, U1.1 (Vref), U1.8 (VDD)
unnamed: P2.3, U1.2 (Vin+)
unnamed: P3.5, P4.1, U2.1 (Vref), U2.8 (VDD)
unnamed: P4.3, U2.2 (Vin+)
unnamed: P5.5, P6.1, U3.1 (Vref), U3.8 (VDD)
unnamed: P6.3, U3.2 (Vin+)
unnamed: P7.5, P8.1, U4.1 (Vref), U4.8 (VDD)
unnamed: P8.3, U4.2 (Vin+)
SCLK_A: P1.2, U1.7 (~CS~)
SCLK_B: P3.2, U2.7 (~CS~)
SCLK_C: P5.2, U3.7 (~CS~)
SCLK_D: P7.2, U4.7 (~CS~)
SS_A: P1.4, U1.5 (SCK)
SS_B: P3.4, U2.5 (SCK)
SS_C: P5.4, U3.5 (SCK)
SS_D: P7.4, U4.5 (SCK)

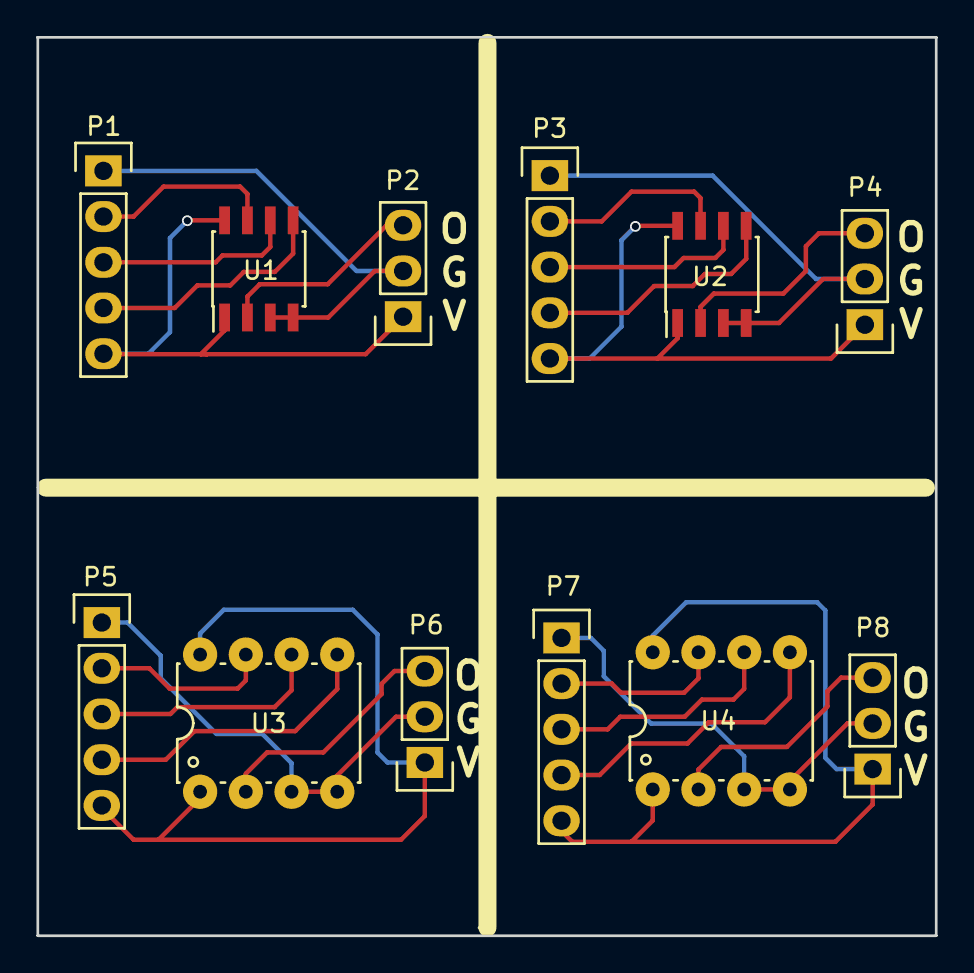
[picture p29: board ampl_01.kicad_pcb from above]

Board: 2 copper layers, 49.9 x 49.9 mm, 12 parts (0 on the bottom side), 24 nets.

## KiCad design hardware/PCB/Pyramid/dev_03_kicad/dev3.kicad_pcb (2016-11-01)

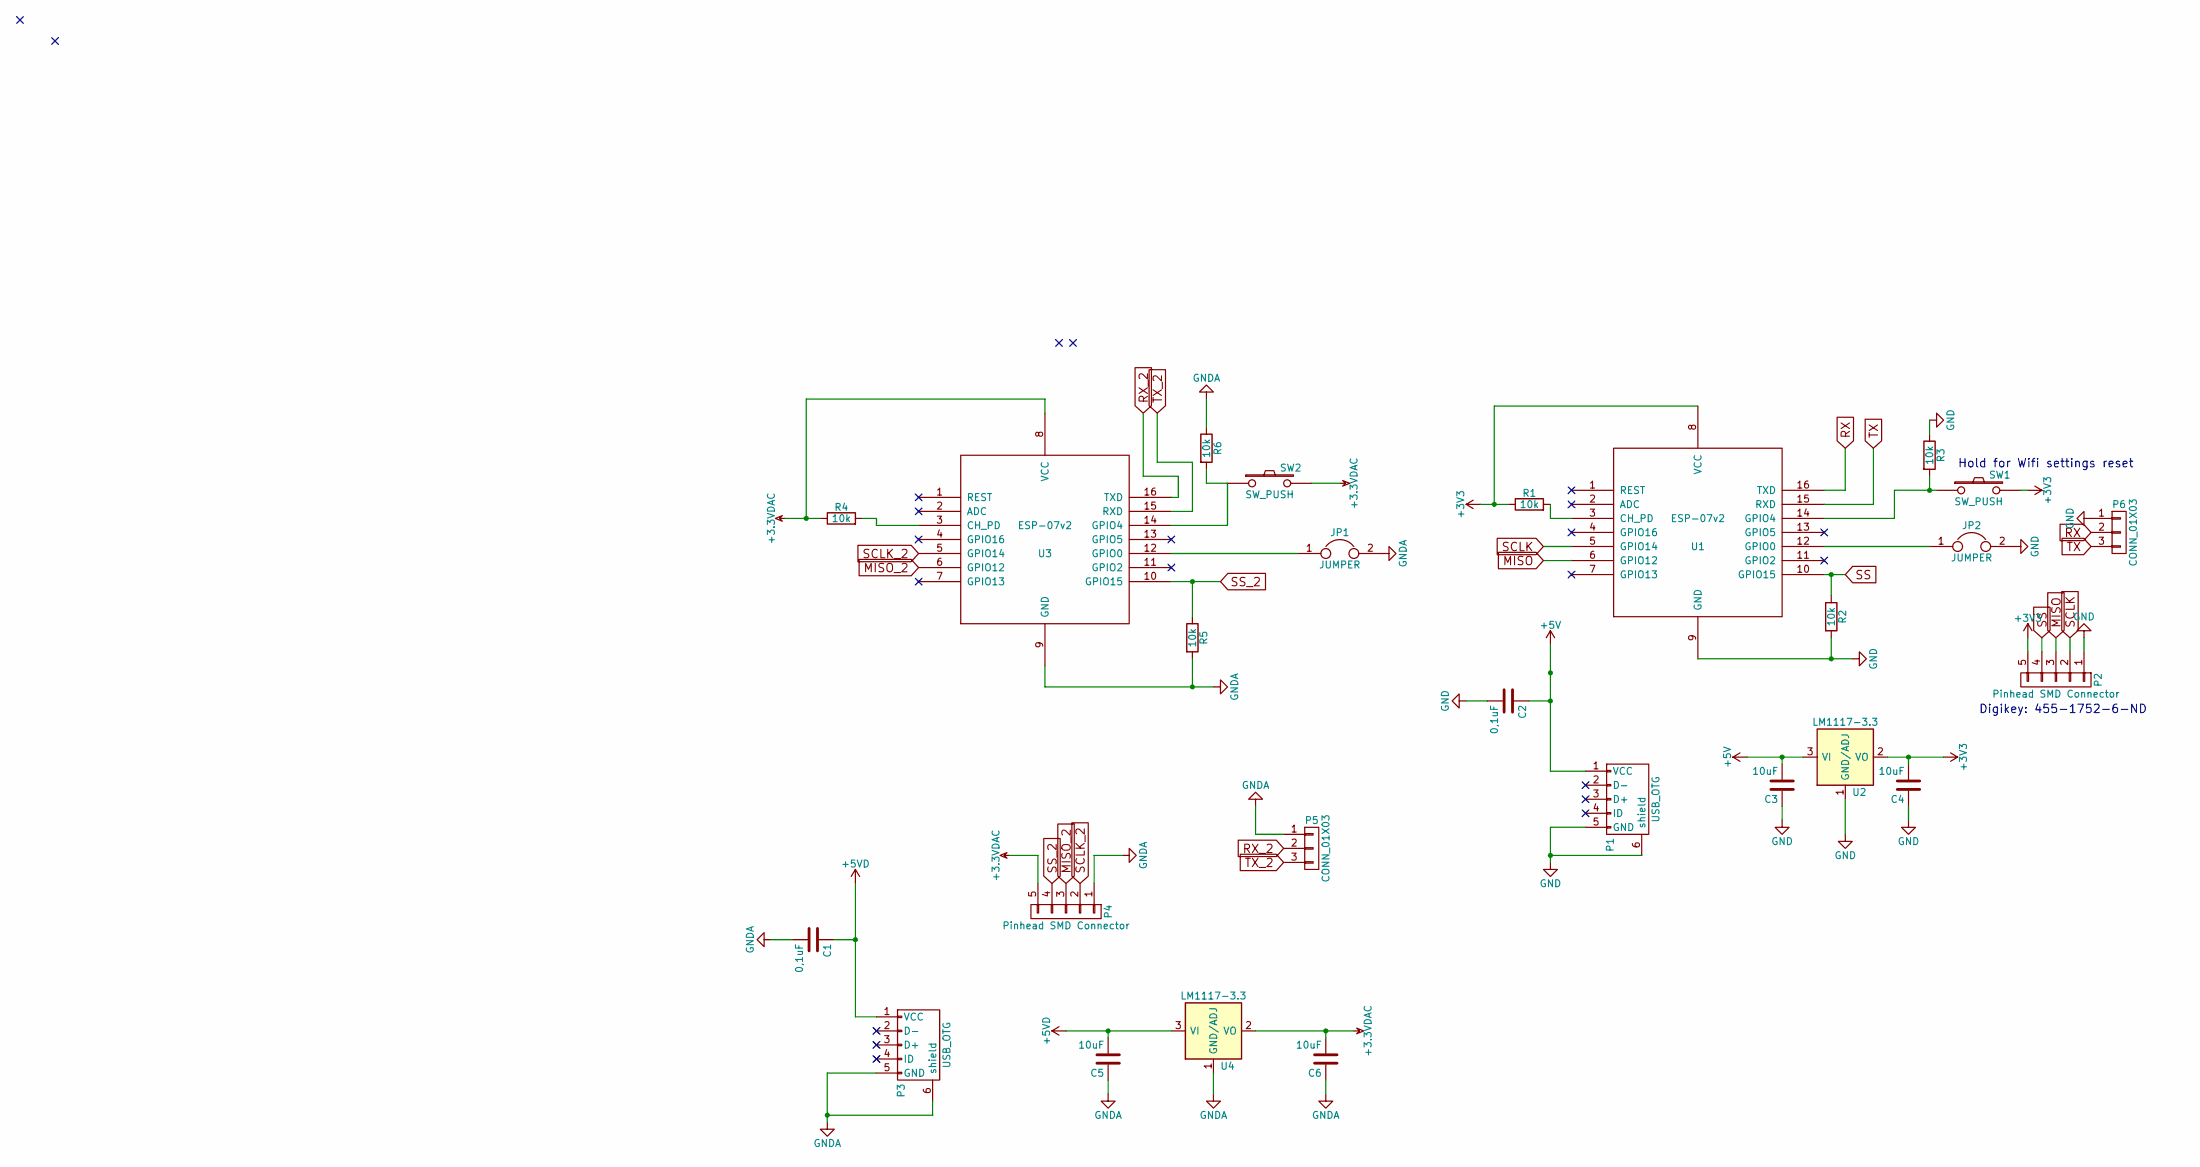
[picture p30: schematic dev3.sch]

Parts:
C1, C2: 0,1uF; C_0805
C3, C4, C5, C6: 10uF; C_0805
JP1, JP2: JUMPER; Pin_Header_Straight_1x02
P1, P3: USB_OTG; USB_Mini-B_AS
P2, P4: Pinhead SMD Connector; Pin_Header_Straight_1x05
P5, P6: CONN_01X03; Socket_Strip_Straight_1x03
R1, R2, R3, R4, R5, R6: 10k; R_0805
SW1, SW2: SW_PUSH; SW_SPST_EVPBF
U1, U3: ESP-07v2
U2, U4: LM1117-3.3; SOT-223

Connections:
+3.3VDAC: C6.2, P4.5, R4.1, SW2.2, U3.8 (VCC), U4.2 (VO), U4.4 (VO)
+3V3: C4.2, P2.5, R1.1, SW1.2, U1.8 (VCC), U2.2 (VO), U2.4 (VO)
+5V: C2.1, C3.2, P1.1 (VCC), U2.3 (VI)
+5VD: C1.1, C5.2, P3.1 (VCC), U4.3 (VI)
GND: C2.2, C3.1, C4.1, JP2.2, P1.5 (GND), P1.6 (shield), P2.1, P6.1, R2.2, R3.1, U1.9 (GND), U2.1 (GND/ADJ)
GNDA: C1.2, C5.1, C6.1, JP1.2, P3.5 (GND), P3.6 (shield), P4.1, P5.1, R5.2, R6.1, U3.9 (GND), U4.1 (GND/ADJ)
MISO: P2.3, U1.6 (GPIO12)
MISO_2: P4.3, U3.6 (GPIO12)
unnamed: JP1.1, U3.12 (GPIO0)
unnamed: JP2.1, U1.12 (GPIO0)
unnamed: R1.2, U1.3 (CH_PD)
unnamed: R3.2, SW1.1, U1.14 (GPIO4)
unnamed: R4.2, U3.3 (CH_PD)
unnamed: R6.2, SW2.1, U3.14 (GPIO4)
RX: P6.2, U1.16 (TXD)
RX_2: P5.2, U3.16 (TXD)
SCLK: P2.2, U1.5 (GPIO14)
SCLK_2: P4.2, U3.5 (GPIO14)
SS: P2.4, R2.1, U1.10 (GPIO15)
SS_2: P4.4, R5.1, U3.10 (GPIO15)
TX: P6.3, U1.15 (RXD)
TX_2: P5.3, U3.15 (RXD)

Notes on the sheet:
Digikey: 455-1752-6-ND
Hold for Wifi settings reset

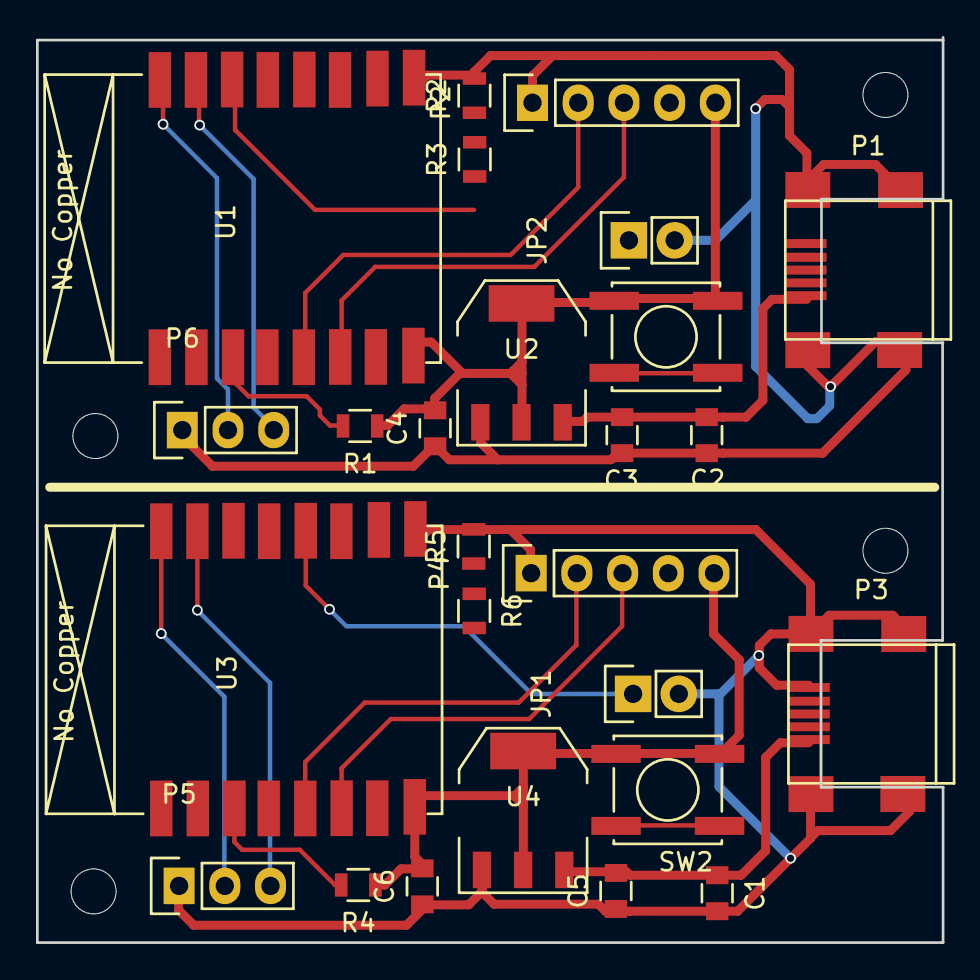
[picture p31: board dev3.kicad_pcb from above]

Board: 2 copper layers, 50.3 x 50.3 mm, 26 parts (0 on the bottom side), 22 nets.

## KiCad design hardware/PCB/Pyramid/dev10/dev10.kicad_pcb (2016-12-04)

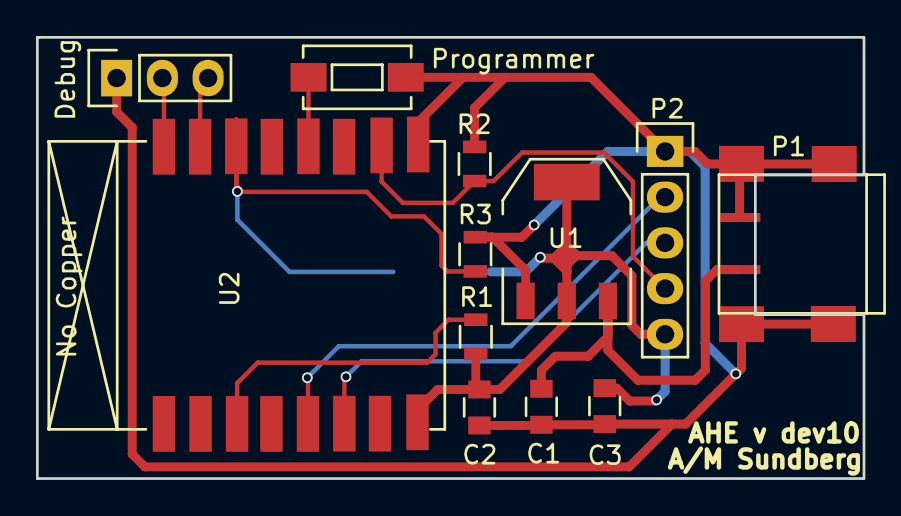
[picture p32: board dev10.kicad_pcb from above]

Board: 2 copper layers, 45.9 x 24.5 mm, 13 parts (1 on the bottom side), 11 nets.

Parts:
C1, C2: C; C_0805
C3: ,1uF; C_0805
Debug: Debug; Pin_Header_Straight_1x03
P1: Power; USB_Mini-B_AS
P2: Audio; Pin_Header_Straight_1x05
Programmer: Program; SW_SPST_EVQPE1
R1, R2, R3: 10k; R_0805
SW1: WifiRst; SW_SPST_EVQPE1
U1: LM1117-3.3; SOT-223
U2: ESP-07v2

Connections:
+5V: C1.1, P1.1, U1.3
GND: C1.2, C2.2, C3.1, Debug.1, P1.5, P1.6, P2.1, Programmer.2, R2.2, R3.1, U1.1, U2.9
MISO: P2.3, U2.6
unnamed: Programmer.1, U2.12
unnamed: R1.1, U2.3
unnamed: R3.2, SW1.1, U2.14
RX: Debug.2, U2.16
SCLK: P2.2, U2.5
SS: P2.4, R2.1, U2.10
TX: Debug.3, U2.15
VCC: C2.1, C3.2, P2.5, R1.2, SW1.2, U1.2, U1.4, U2.8

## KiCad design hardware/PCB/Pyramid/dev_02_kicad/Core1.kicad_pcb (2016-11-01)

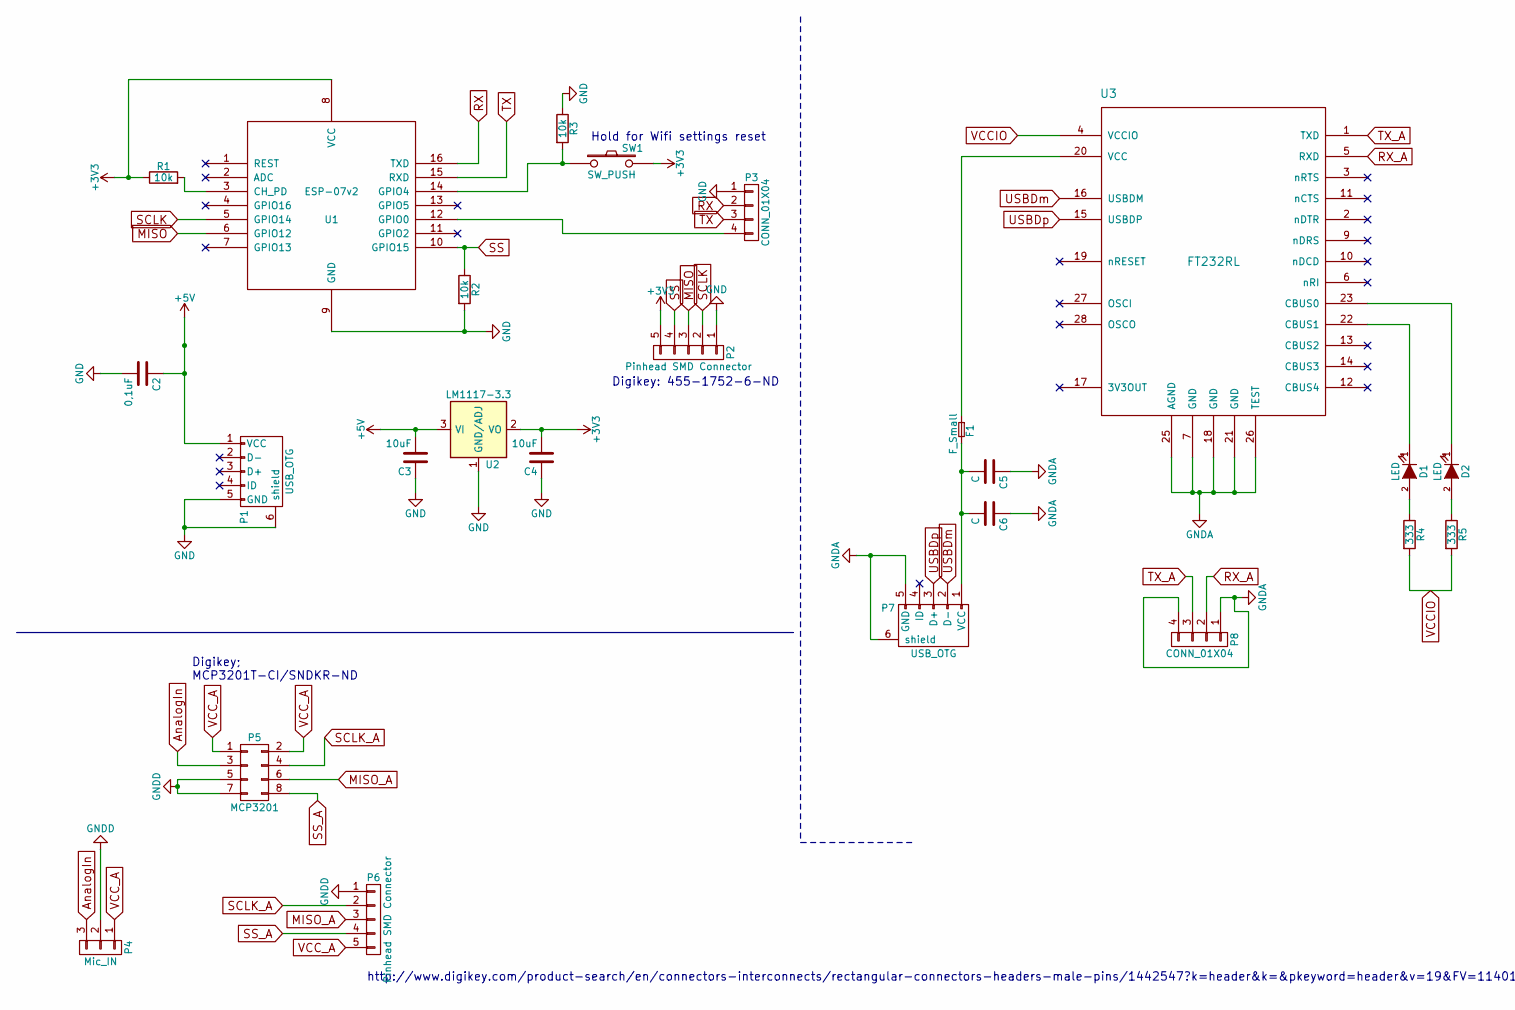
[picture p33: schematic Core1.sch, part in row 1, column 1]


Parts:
C2: 0,1uF; C_0805
C3, C4: 10uF; C_0805
C5, C6: C; C_0805
D1, D2: LED; LED_0805
F1: F_Small; SMD-1206_Pol
P1, P7: USB_OTG; USB_Mini-B
P2, P6: Pinhead SMD Connector; Pin_Header_Straight_1x05
P3, P8: CONN_01X04; Pin_Header_Straight_1x04
P4: Mic_IN; Pin_Header_Straight_1x03
P5: MCP3201; SOIC-8_3.9x4.9mm_Pitch1.27mm
R1, R2, R3: 10k; R_0805
R4, R5: 333; R_0805
SW1: SW_PUSH; SW_SPST_EVPBF
U1: ESP-07v2
U2: LM1117-3.3; SOT-223
U3: FT232RL; SSOP-28_5.3x10.2mm_Pitch0.65mm

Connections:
+3V3: C4.2, P2.5, R1.1, SW1.2, U1.8 (VCC), U2.2 (VO), U2.4 (VO)
+5V: C2.1, C3.2, P1.1 (VCC), U2.3 (VI)
AnalogIn: P4.3, P5.3
GND: C2.2, C3.1, C4.1, P1.5 (GND), P1.6 (shield), P2.1, P3.1, R2.2, R3.1, U1.9 (GND), U2.1 (GND/ADJ)
GNDA: C5.1, C6.1, P7.5 (GND), P7.6 (shield), P8.1, P8.4, U3.7 (GND), U3.18 (GND), U3.21 (GND), U3.25 (AGND), U3.26 (TEST)
GNDD: P4.2, P5.5, P5.7, P6.1
MISO: P2.3, U1.6 (GPIO12)
MISO_A: P5.6, P6.3
unnamed: C5.2, C6.2, F1.2, P7.1 (VCC)
unnamed: D1.1 (K), U3.22 (CBUS1)
unnamed: D1.2 (A), R4.1
unnamed: D2.1 (K), U3.23 (CBUS0)
unnamed: D2.2 (A), R5.1
unnamed: F1.1, U3.20 (VCC)
unnamed: P3.4, U1.12 (GPIO0)
unnamed: R1.2, U1.3 (CH_PD)
unnamed: R3.2, SW1.1, U1.14 (GPIO4)
RX: P3.2, U1.16 (TXD)
RX_A: P8.2, U3.5 (RXD)
SCLK: P2.2, U1.5 (GPIO14)
SCLK_A: P5.4, P6.2
SS: P2.4, R2.1, U1.10 (GPIO15)
SS_A: P5.8, P6.4
TX: P3.3, U1.15 (RXD)
TX_A: P8.3, U3.1 (TXD)
USBDm: P7.2 (D-), U3.16 (USBDM)
USBDp: P7.3 (D+), U3.15 (USBDP)
VCCIO: R4.2, R5.2, U3.4 (VCCIO)
VCC_A: P4.1, P5.1, P5.2, P6.5

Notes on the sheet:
Digikey: 455-1752-6-ND
Hold for Wifi settings reset
Digikey; MCP3201T-CI/SNDKR-ND
http://www.digikey.com/product-search/en/connectors-interconnects/rectangular-connectors-headers-male-pins/1442547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


Board: 2 copper layers, 50.3 x 44.5 mm, 25 parts (0 on the bottom side), 29 nets.

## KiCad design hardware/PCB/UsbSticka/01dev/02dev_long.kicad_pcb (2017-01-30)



Board: 2 copper layers, 17.7 x 51.8 mm, 27 parts (14 on the bottom side), 20 nets.

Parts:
C1, C2, C4, C5, C6, C7, C8: 0,1; C_0805
C3: 10; C_0805
C9: 10uF; C_0805
FB1: FERRITE; C_0805_HandSoldering
P1: USB_B; USB_A_AS
P2: MIC; Socket_Strip_Straight_1x02
P3: Debug; Socket_Strip_Straight_1x03
R1, R2: 2,2k; R_0805
R3, R4, R5: 10k; R_0805
R6, R7, R8: 1k; R_0805
SW1, SW2: SW_PUSH; SW_SPST_EVQPE1
U1: LM1117-3.3; SOT-223
U2: MAX9813; SOT-23-8
U3: ESP-07v2; ESP-07_AS
U4: MCP3201; PDIP-8

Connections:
+5V: C1.1, C7.2, FB1.2, P1.1, U1.3, U4.8
ANALOG: C2.1, U2.1
GND: C1.2, C3.2, C5.1, C6.1, C7.1, C8.1, C9.2, P1.4, P1.5, P2.1, P3.1, R4.2, R5.1, R8.2, SW1.2, U1.1, U2.2, U3.9, U4.3, U4.4
MISO: R6.1, R7.1, U3.6
unnamed: C2.2, U4.2
unnamed: C4.1, P2.2, R1.2
unnamed: C4.2, C8.2, U2.6
unnamed: C5.2, C6.2, C9.1, FB1.1, R2.1, U2.3, U2.8, U4.1
unnamed: P3.2, U3.16
unnamed: P3.3, U3.15
unnamed: R1.1, U2.7
unnamed: R2.2, U2.4
unnamed: R3.1, U3.3
unnamed: R5.2, SW2.1, U3.14
unnamed: R6.2, U4.6
unnamed: R7.2, R8.1
unnamed: SW1.1, U3.12
SCLK: U3.5, U4.7
SS: R4.1, U3.10, U4.5
VCC: C3.1, R3.2, SW2.2, U1.2, U1.4, U3.8

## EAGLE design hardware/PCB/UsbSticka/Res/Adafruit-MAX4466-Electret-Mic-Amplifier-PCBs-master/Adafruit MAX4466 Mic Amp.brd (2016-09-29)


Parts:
C1: 0.1µF; 0805
C2: 0.01uF; 0805
C3: 100pF; 0805
C4: 10uF; 0805
FB1, FB2: FERRITE; 0805
FID1, FID2: FIDUCIAL""; FIDUCIAL_1MM
JP1: HEADER-1X376MIL; 1X03_ROUND_76
Q1: CMA-4544PF-W; ELECTRET_9.7
R1, R2, R5: 1K; 0805
R3, R4: 1M; 0805
R7: 22K; 0805
U1: MAX4466EXK+T; SC70-5
U$11, U$14: MOUNTINGHOLE2.5; MOUNTINGHOLE_2.5_PLATED
VR1: TC33X-2-104E (100K); TRIMPOT_BOURNS_TC33X-2

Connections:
AGND: C1.2, C4.2, FB1.2, Q1.- (1), R3.1, U1.2 (GND)
AVCC: FB2.1, R2.2, R4.2, U1.5 (VCC)
GND: FB1.1, JP1.2
unnamed: C3.2, R5.2, R7.1, U1.3 (IN-)
unnamed: R7.2, VR1.3 (E)
unnamed: C2.1, Q1.+ (2), R1.1
unnamed: C1.1, R1.2, R2.1
unnamed: C2.2, R3.2, R4.1, U1.1 (IN+)
unnamed: C3.1, JP1.3, U1.4 (OUT), VR1.1 (A), VR1.2 (S)
unnamed: C4.1, R5.1
VCC: FB2.2, JP1.1

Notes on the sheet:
Gain =
VR1+R7
= ~25-125x gain
Low pass F3db = 1/R5*C4*2pi



Board: 2 copper layers, 14.0 x 21.6 mm, 22 parts (2 on the bottom side), 11 nets.

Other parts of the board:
U$16, U$17: ADAFRUIT_2.5MM

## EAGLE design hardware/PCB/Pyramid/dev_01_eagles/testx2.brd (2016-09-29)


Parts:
C1, C4: 0,1; 0805-CAP
C2, C3: 10uF; 0805-CAP
C5: CAP_; AXIAL-5MM
F1: 500mA; PTC-1206
J1_1, J1_2: JST-PH_5-PIN_HEADER; JST_B5B-PH_HEADER
J2_1: JST-PH_3-PIN_HEADER; JST_B3B-PH_HEADER
JST_1: JST-PH_3-PIN_HEADER; JST_B3B-PH_HEADER
LED1: Red; SML0805
LED2: Green; SML0805
MCP3201: DIL8; DIL08
MIC: PINHD-1X03_2.54-S; 1X03-S
PRG: JP1E; JP1
R1, R2: 330; 0805
R3, R4, R11: 10K; 0805
S1: SWITCH-MOMENTARY-2PTH; TACTILE-PTH
U1: FT232R; SSOP28DB
U2: V_REG_LM1117SOT223; SOT223
U$1: ESP07-16PIN
USB1, USB2: USB-MB-S

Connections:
5V: C3.1, C5.P$2 (2), U2.3 (IN), USB2.VBUS
AN+: MCP3201.2, MIC.3
CLK: J1_1.P4 (4), U$1.GPIO14
CLK_A: J1_2.P4 (4), MCP3201.7
CS: J1_1.P2 (2), U$1.GPIO15
CS_A: J1_2.P2 (2), MCP3201.5
CTS: U1.11 (CTS)
DCD: U1.10 (DCD)
DSR: U1.9 (DSR)
DTR: U1.2 (DTR)
GND: C1.2, C2.2, JST_1.P1 (1), U1.7 (GND7), U1.18 (GND18), U1.21 (GND21), U1.25 (AGND), U1.26 (TEST), USB1.GND
GND2: C3.2, C4.2, C5.P$1 (1), J1_1.P1 (1), J2_1.P1 (1), PRG.2, R4.1, R11.1, U2.1 (ADJ), U$1.GND, USB2.GND
GND3: J1_2.P1 (1), MCP3201.3, MCP3201.4, MIC.2
MISO: J1_1.P3 (3), U$1.GPIO12
MISO_A: J1_2.P3 (3), MCP3201.6
unnamed: LED1.A, R1.1
unnamed: LED2.A, R2.1
unnamed: F1.1, USB1.VBUS
unnamed: R3.1, U$1.CH_PD
unnamed: J2_1.P2 (2), U$1.TX
unnamed: R4.2, U$1.GPIO2
unnamed: PRG.1, U$1.GPIO0
unnamed: J2_1.P3 (3), U$1.RX
unnamed: R11.2, S1.1, U$1.GPIO4
PWREN: U1.14 (PWREN)
RI: U1.6 (RI)
RTS: U1.3 (RTS)
RXD: JST_1.P2 (2), U1.5 (RXD)
RXLED: LED2.C, U1.22 (RXLED)
SLEEP: U1.12 (SLEEP)
TXD: JST_1.P3 (3), U1.1 (TXD)
TXDEN: U1.13 (TXDEN)
TXLED: LED1.C, U1.23 (TXLED)
USB_D+: U1.15 (USBDP), USB1.D+
USB_D-: U1.16 (USBDM), USB1.D-
VCC: C4.1, J1_1.P5 (5), R3.2, S1.3 (2), U2.2 (OUT), U2.4 (OUT), U$1.VCC
VCCIO: R1.2, R2.2, U1.4 (VCCIO)
VCC_A: J1_2.P5 (5), MCP3201.1, MCP3201.8, MIC.1
VCC_P: C1.1, C2.1, F1.2, U1.20 (VCC)

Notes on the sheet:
Programmer
AHE
ADC
Analog inputs


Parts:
C6: 0.1µF; 0805
C7: 0.01uF; 0805
C8: 100pF; 0805
C9: 10uF; 0805
FB1, FB2: FERRITE; 0805
FID1, FID2: FIDUCIAL""; FIDUCIAL_1MM
JP3: HEADER-1X376MIL; 1X03_ROUND_76
Q1: CMA-4544PF-W; ELECTRET_9.7
R5, R6, R7: 1K; 0805
R8, R9: 1M; 0805
R10: 22K; 0805
U3: MAX4466EXK+T; SC70-5
U$16, U$17: MOUNTINGHOLE2.5; MOUNTINGHOLE_2.5_PLATED
VR1: TC33X-2-104E (100K); TRIMPOT_BOURNS_TC33X-2

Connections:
AGND: C6.2, C9.2, FB1.2, Q1.- (1), R8.1, U3.2 (GND)
AVCC: FB2.1, R6.2, R9.2, U3.5 (VCC)
GND_MIC: FB1.1
unnamed: C7.1, Q1.+ (2), R5.1
unnamed: C6.1, R5.2, R6.1
unnamed: C7.2, R8.2, R9.1, U3.1 (IN+)
unnamed: C8.1, JP3.3, U3.4 (OUT), VR1.1 (A), VR1.2 (S)
unnamed: C8.2, R7.2, R10.1, U3.3 (IN-)
unnamed: C9.1, R7.1
unnamed: R10.2, VR1.3 (E)
VCC_MIC: FB2.2, JP3.1

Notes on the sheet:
Gain =
VR1+R7
= ~25-125x gain
Low pass F3db = 1/R5*C4*2pi



Board: 2 copper layers, 50.4 x 50.2 mm, 48 parts (3 on the bottom side), 40 nets.

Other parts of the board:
U$19, U$20: ADAFRUIT_2.5MM

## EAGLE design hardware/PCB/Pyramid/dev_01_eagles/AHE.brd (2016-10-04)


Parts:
AMS1117: V_REG_LM1117SOT223; SOT223
C1, C5: 0,1uF; 0805-CAP
C2, C3: 10uF; 0805-CAP
C4: 0,1; 0805-CAP
F1: 500mA; PTC-1206
J1: JST-PH_5-PIN_HEADER; JST_B5B-PH_HEADER
PRG: JP1E; JP1
R1, R2: 330; 0805
R3, R4, R5: 10K; 0805
RX: Green; SML0805
S2: SWITCH-MOMENTARY-2SMD-REDUNDANT; TACTILE-SWITCH-SMD
TX: Red; SML0805
U1: FT232R; SSOP28DB
U$1: ESP07-16PIN
USB1: USB-MB-S

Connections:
CLK: J1.P4 (4), U$1.GPIO14
CS: J1.P2 (2), U$1.GPIO15
CTS: U1.11 (CTS)
DCD: U1.10 (DCD)
DSR: U1.9 (DSR)
DTR: C5.1, U1.2 (DTR)
GND: AMS1117.1 (ADJ), C1.2, C2.2, C3.2, C4.2, J1.P1 (1), PRG.2, R4.1, R5.1, U1.7 (GND7), U1.18 (GND18), U1.21 (GND21), U1.25 (AGND), U1.26 (TEST), U$1.GND, USB1.GND
MISO: J1.P3 (3), U$1.GPIO12
unnamed: R1.1, TX.A
unnamed: R2.1, RX.A
unnamed: F1.1, USB1.VBUS
unnamed: R3.1, U$1.CH_PD
unnamed: C5.2, U$1.REST (RESET)
unnamed: R4.2, U$1.GPIO2
unnamed: PRG.1, U$1.GPIO0
unnamed: R5.2, S2.1, S2.2 (1), U$1.GPIO4
PWREN: U1.14 (PWREN)
RI: U1.6 (RI)
RTS: U1.3 (RTS)
RXD: U1.5 (RXD), U$1.TX
RXLED: RX.C, U1.22 (RXLED)
SLEEP: U1.12 (SLEEP)
TXD: U1.1 (TXD), U$1.RX
TXDEN: U1.13 (TXDEN)
TXLED: TX.C, U1.23 (TXLED)
USB_D+: U1.15 (USBDP), USB1.D+
USB_D-: U1.16 (USBDM), USB1.D-
VCC: AMS1117.2 (OUT), AMS1117.4 (OUT), C4.1, J1.P5 (5), R3.2, S2.3 (2), S2.4 (2), U$1.VCC
VCCIO: R1.2, R2.2, U1.4 (VCCIO)
VCC_P: AMS1117.3 (IN), C1.1, C2.1, C3.1, F1.2, U1.20 (VCC)

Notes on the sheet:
Programmer
AHE
CAP VCC- GND


Board: 2 copper layers, 50.0 x 50.2 mm, 20 parts (0 on the bottom side), 22 nets.

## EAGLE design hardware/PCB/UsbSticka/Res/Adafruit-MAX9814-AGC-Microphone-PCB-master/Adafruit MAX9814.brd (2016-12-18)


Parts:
C1, C5: 2.2uF; C0805K
C2, C9: 0.1uF; C0805K
C8: 0.47uF; C0805K
FB1, FB2: FERRITE; 0805
J2: HEADER-1X576MIL; 1X05_ROUND_76
Q1: CMA-4544PF-W; 9.7ELECTRET
R1: 150k; R0805
R2: 100k; R0805
R3: 2.2K; R0805
U$1: MAX9814TDFN14; TDFN14_3X3MM
U$2, U$3: FIDUCIAL; FIDUCIAL_1MM
U$4, U$5: MOUNTINGHOLE2.0; MOUNTINGHOLE_2.0_PLATED

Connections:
A/R: J2.5, U$1.P$9 (A/R)
GAIN: J2.3, U$1.P$10 (GAIN)
GND: C1.2, C2.2, C5.2, C8.2, FB2.2, Q1.- (1), R2.1, U$1.P$4 (NC1), U$1.P$7 (GND), U$1.P$11 (NC2), U$1.P$THERMAL (EP)
INPUT: C9.2, Q1.+ (2), R3.1
unnamed: FB1.1, J2.2
unnamed: FB2.1, J2.1
unnamed: C9.1, U$1.P$8 (MICIN)
unnamed: C8.1, U$1.P$12 (BIAS)
unnamed: C2.1, U$1.P$1 (CT)
unnamed: C5.1, U$1.P$3 (CG)
unnamed: R1.1, R2.2, U$1.P$14 (TH)
unnamed: R1.2, R3.2, U$1.P$13 (MICBIAS)
OUTPUT: J2.4, U$1.P$6 (MICOUT)
VDD: C1.1, FB1.2, U$1.P$2 (/SHDN), U$1.P$5 (VDD)


Board: 2 copper layers, 25.4 x 14.1 mm, 18 parts (1 on the bottom side), 14 nets.

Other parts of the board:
U$6: ADAFRUIT_3.5MM

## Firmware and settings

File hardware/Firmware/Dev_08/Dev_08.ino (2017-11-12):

//Libraries
#include <ESP8266WiFi.h>          //https://github.com/esp8266/Arduino
#include <DNSServer.h>
#include <ESP8266WebServer.h>
#include <WiFiManager.h>         //https://github.com/tzapu/WiFiManager
//#include <WiFiUDP.h>
#define WIFIUDP_H
#include <SPI.h>

#define SS 13
#define PIN_SPI_SS (13)
#define PIN_SPI_MOSI (15)

//UDP Variabler
const int UDP_PACKET_SIZE = 64;
char incomingPacket[UDP_PACKET_SIZE];
char incomingUDP[UDP_PACKET_SIZE];

WiFiUDP udp;
IPAddress ipServer(0, 0, 0, 0);
unsigned int udpRecievePort = 11319;
unsigned int udpSoundPort = 11318;
unsigned int udpRespondPort = 11320;
boolean sync = false;

//Microfon variabler.
unsigned long lastRequest = 0;
unsigned long lastPing;
unsigned long now;

// ADC
uint16_t adc_buf[2][640]; // ADC data buffer, double buffered
int current_adc_buf; // which data buffer is being used for the ADC (the other is being sent)
unsigned int adc_buf_pos; // position in the ADC data buffer
int send_samples_now; // flag to signal that a buffer is ready to be sent

#define SILENCE_EMA_WEIGHT 1024
#define ENVELOPE_EMA_WEIGHT 2
int32_t silence_value = 2048; // computed as an exponential moving average of the signal
uint16_t envelope_threshold = 4; // envelope threshold to trigger data sending
uint32_t send_sound_util = 0; // date until sound transmission ends after an envelope threshold has triggered sound transmission
unsigned int stop_sound_after  = 10000;
int enable_highpass_filter = 1;

// Övrigt
const int resetPIN = 5;     // the number of the pushbutton pin
int debug_threshold = 0;


void setup() {

  //Debug
  Serial.begin(115200);
  Serial.println("Starting! Firmware: Dev_08");

  //Klientnamn på routern.
  wifi_station_set_hostname("AllHearingEar");

  //WiFiManager startar
  WiFiManager wifiManager;

  // initialize the pushbutton pin as an input:
  pinMode(resetPIN, INPUT);

  // initialize manual SS/CS for MCP3201:

  delay(1000);

  if (digitalRead(resetPIN)) {
    //Reset settings
    Serial.println("Reseting WIFI");
    //Använd denna om du vill plocka bort SSID och lösernord.
    wifiManager.resetSettings();
  }

  //Hämta tidigare sparade SSID/Lösen eller starta portal om det behövs.
  wifiManager.autoConnect("AllHearingEar");

  //Starta SPI för digital input.
  spiBegin();

  // Starta UDP protokoll.
  udp.begin(udpRecievePort);

  // Vänta inkommande sync från servern
  Serial.print("Waiting sync.");
  while (sync == false) {
    UdpRecieveSync();
  }

  //Aktivera hårdvarutimer för 12,5kHz.
  timer1_isr_init();
  timer1_attachInterrupt(sample_isr);
  timer1_enable(TIM_DIV16, TIM_EDGE, TIM_LOOP);
  timer1_write(clockCyclesPerMicrosecond() / 16 * 50); //80us = 12.5kHz sampling freq

  Serial.print("Sync - IP Server: ");
  Serial.println(ipServer);
}

void loop()
{

  UdpRecieveData();

  //Sync failed - Waiting for new
  while (sync == false) {
    UdpRecieveSync();
  }

  if (send_samples_now) {
    /* We're ready to send a buffer of samples over wifi. Decide if it has to happen or not,
       that is, if the sound level is above a certain threshold. */

    // Update silence and envelope computations
    uint16_t number_of_samples = sizeof(adc_buf[0]) / sizeof(adc_buf[0][0]);
    int32_t accum_silence = 0;
    int32_t envelope_value = 0;

    uint8_t *writeptr = (uint8_t *)(&adc_buf[!current_adc_buf][0]);
    uint16_t *readptr;
    uint16_t last = 0;
    for (unsigned int i = 0; i < number_of_samples; i++) {
      readptr = &adc_buf[!current_adc_buf][i];
      int32_t val = *readptr;
      int32_t rectified;

      if (enable_highpass_filter) {
        *readptr = filterloop(val) + 2048;
        val = *readptr;
      }

      rectified = abs(val - silence_value);

      accum_silence += val;
      envelope_value += rectified; //TA BORT??

      // delta7-compress the data
      writeptr = delta7_sample(last, readptr, writeptr);
      last = val;
    }
    accum_silence /= number_of_samples;
    envelope_value /= number_of_samples;
    silence_value = (SILENCE_EMA_WEIGHT * silence_value + accum_silence) / (SILENCE_EMA_WEIGHT + 1);
    envelope_value = envelope_value;

      if (debug_threshold > 0) {
        Serial.print("Threshold val "); Serial.println(envelope_value);
        debug_threshold++;
        if (debug_threshold == 1000) {
          debug_threshold = 0;
        }
      }

    if (envelope_value > envelope_threshold) {
      send_sound_util = millis() + stop_sound_after;
    }

    if (millis() < send_sound_util) {
      udp.beginPacket(ipServer, udpSoundPort);
      udp.write((const uint8_t *)(&adc_buf[!current_adc_buf][0]), writeptr - (uint8_t *)&adc_buf[!current_adc_buf][0]);
      udp.endPacket();
    }
    send_samples_now = 0;
  }

  // If not sending anything, add a delay to enable modem sleep
  if (millis() > send_sound_util) {
    delay(10);
  }
}

void UdpSend(byte msg)
{
  udp.beginPacket(ipServer, udpRespondPort);
  udp.write(msg);
  Serial.print("Sending UDP: ");   Serial.println(msg);
  udp.endPacket();
}


void UdpRecieveSync() {

  unsigned long now = millis();
  if ((ipServer < 1) && (now - lastRequest) > 5000) {
    lastRequest = now;
    Serial.print(".");
  }

  int packetSize = udp.parsePacket();
  if (packetSize) {
    ipServer = udp.remoteIP();
    int len = udp.read(incomingPacket, 255);
    sync = true;
    if (len > 0)
    {
      incomingPacket[len] = 0;
    }
    UdpSend(49);
  }
}

void UdpRecieveData()
{
  int packetSizeD = udp.parsePacket();
  if (packetSizeD) {
    udp.read(incomingUDP, 255);
    uint8_t swUDP = incomingUDP[0] - '0';

    Serial.print("Switching: "); Serial.println(swUDP);
    //0 = SYNC
    //1 = ACK
    //2 = VOLYM
    //3 = Debug (Show envelope value)
    //4 = Set sync to 0

    switch (swUDP) {
      case 0:
        UdpSend(49);
        break;
      case 1:
        //ACK from software - should not be used.
        break;
      case 2:
        //Sätt volym.
        Serial.print("RawVolume: "); Serial.println(incomingUDP[1] - '0');
        if (incomingUDP[1] - '0' == 0) {
          envelope_threshold = 2; //Rör sig
        }
        if (incomingUDP[1] - '0' == 1) {
          envelope_threshold = 4; //Gnyr
        }
        if (incomingUDP[1] - '0' == 2) {
          envelope_threshold = 30; //Skriker
        }
        if (incomingUDP[1] - '0' == 3) {
          envelope_threshold = 60; //Världskrig
        }
        Serial.print("Volym: "); Serial.println(envelope_threshold);
        break;
      case 3:
      
        if (debug_threshold  == 0) {
          debug_threshold = 1;
        }
        else {
          debug_threshold = 0;
        }
        break;
      case 4:
        Serial.print("Waiting sync.");
        sync = false;
        break;
      default:
        Serial.println("No command found");
        break;
    }
  }
}

static inline void setDataBits(uint16_t bits) {
  const uint32_t mask = ~((SPIMMOSI << SPILMOSI) | (SPIMMISO << SPILMISO));
  bits--;
  SPI1U1 = ((SPI1U1 & mask) | ((bits << SPILMOSI) | (bits << SPILMISO)));
}

void spiBegin(void)
{
  SPI.begin();
  SPI.setDataMode(SPI_MODE0);
  SPI.setBitOrder(MSBFIRST);
  SPI.setClockDivider(SPI_CLOCK_DIV8);
  SPI.setHwCs(1);
  setDataBits(16);
}

#define ICACHE_RAM_ATTR     __attribute__((section(".iram.text")))
/* SPI code based on the SPI library */
static inline ICACHE_RAM_ATTR uint16_t transfer16(void) {
  union {
    uint16_t val;
    struct {
      uint8_t lsb;
      uint8_t msb;
    };
  } out;

  // Transfer 16 bits at once, leaving HW CS low for the whole 16 bits
  while (SPI1CMD & SPIBUSY) {}
  SPI1W0 = 0;
  SPI1CMD |= SPIBUSY;
  while (SPI1CMD & SPIBUSY) {}

  /* Follow MCP3201's datasheet: return value looks like this:
  xxxBA987 65432101
  We want
  76543210 0000BA98
  So swap the bytes, select 12 bits starting at bit 1, and shift right by one.
  */

  out.val = SPI1W0 & 0xFFFF;
  uint8_t tmp = out.msb;
  out.msb = out.lsb;
  out.lsb = tmp;

  out.val &= (0x0FFF << 1);
  out.val >>= 1;
  //Serial.println(out.val);
  return out.val;
}

void ICACHE_RAM_ATTR sample_isr(void)
{
  uint16_t val;
  // Read a sample from ADC

  val = transfer16();
  adc_buf[current_adc_buf][adc_buf_pos] = val & 0xFFF;
  adc_buf_pos++;

  // If the buffer is full, signal it's ready to be sent and switch to the other one
  if (adc_buf_pos > sizeof(adc_buf[0]) / sizeof(adc_buf[0][0])) {
    adc_buf_pos = 0;
    current_adc_buf = !current_adc_buf;
    send_samples_now = 1;
  }
}

#define NZEROS 5
#define NPOLES 5
#define GAIN   1.129790960e+00f
static float xv[NZEROS + 1], yv[NPOLES + 1];

static float filterloop(float input)
{ for (;;)
  { xv[0] = xv[1]; xv[1] = xv[2]; xv[2] = xv[3]; xv[3] = xv[4]; xv[4] = xv[5];
    xv[5] = input / GAIN;
    yv[0] = yv[1]; yv[1] = yv[2]; yv[2] = yv[3]; yv[3] = yv[4]; yv[4] = yv[5];
    yv[5] =   (xv[5] - xv[0]) + 5 * (xv[1] - xv[4]) + 10 * (xv[3] - xv[2])
              + (  0.7834365141f * yv[0]) + ( -4.1083230157f * yv[1])
              + (  8.6224512099f * yv[2]) + ( -9.0535899276f * yv[3])
              + (  4.7560230574f * yv[4]);
    return yv[5];
  }
}

uint8_t *delta7_sample(uint16_t last, uint16_t *readptr, uint8_t *writeptr)
{
  const uint8_t lowbyte1 = *((uint8_t *)readptr);
  const uint8_t highbyte1 = *((uint8_t *)readptr + 1);
  const uint16_t val = *readptr;
  const int32_t diff = val - last;

  // 7bit delta not wanted, output as-is
  *writeptr++ = highbyte1;
  *writeptr++ = lowbyte1;

  return writeptr;
}

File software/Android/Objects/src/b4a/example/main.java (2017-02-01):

package b4a.example;


import anywheresoftware.b4a.B4AMenuItem;
import android.app.Activity;
import android.os.Bundle;
import anywheresoftware.b4a.BA;
import anywheresoftware.b4a.BALayout;
import anywheresoftware.b4a.B4AActivity;
import anywheresoftware.b4a.ObjectWrapper;
import anywheresoftware.b4a.objects.ActivityWrapper;
import java.lang.reflect.InvocationTargetException;
import anywheresoftware.b4a.B4AUncaughtException;
import anywheresoftware.b4a.debug.*;
import java.lang.ref.WeakReference;

public class main extends Activity implements B4AActivity{
	public static main mostCurrent;
	static boolean afterFirstLayout;
	static boolean isFirst = true;
    private static boolean processGlobalsRun = false;
	BALayout layout;
	public static BA processBA;
	BA activityBA;
    ActivityWrapper _activity;
    java.util.ArrayList<B4AMenuItem> menuItems;
	public static final boolean fullScreen = false;
	public static final boolean includeTitle = false;
    public static WeakReference<Activity> previousOne;

	@Override
	public void onCreate(Bundle savedInstanceState) {
		super.onCreate(savedInstanceState);
		if (isFirst) {
			processBA = new anywheresoftware.b4a.ShellBA(this.getApplicationContext(), null, null, "b4a.example", "b4a.example.main");
			processBA.loadHtSubs(this.getClass());
	        float deviceScale = getApplicationContext().getResources().getDisplayMetrics().density;
	        BALayout.setDeviceScale(deviceScale);
            
		}
		else if (previousOne != null) {
			Activity p = previousOne.get();
			if (p != null && p != this) {
                BA.LogInfo("Killing previous instance (main).");
				p.finish();
			}
		}
        processBA.runHook("oncreate", this, null);
		if (!includeTitle) {
        	this.getWindow().requestFeature(android.view.Window.FEATURE_NO_TITLE);
        }
        if (fullScreen) {
        	getWindow().setFlags(android.view.WindowManager.LayoutParams.FLAG_FULLSCREEN,   
        			android.view.WindowManager.LayoutParams.FLAG_FULLSCREEN);
        }
		mostCurrent = this;
        processBA.sharedProcessBA.activityBA = null;
		layout = new BALayout(this);
		setContentView(layout);
		afterFirstLayout = false;
		BA.handler.postDelayed(new WaitForLayout(), 5);

	}
	private static class WaitForLayout implements Runnable {
		public void run() {
			if (afterFirstLayout)
				return;
			if (mostCurrent == null)
				return;
            
			if (mostCurrent.layout.getWidth() == 0) {
				BA.handler.postDelayed(this, 5);
				return;
			}
			mostCurrent.layout.getLayoutParams().height = mostCurrent.layout.getHeight();
			mostCurrent.layout.getLayoutParams().width = mostCurrent.layout.getWidth();
			afterFirstLayout = true;
			mostCurrent.afterFirstLayout();
		}
	}
	private void afterFirstLayout() {
        if (this != mostCurrent)
			return;
		activityBA = new BA(this, layout, processBA, "b4a.example", "b4a.example.main");
        
        processBA.sharedProcessBA.activityBA = new java.lang.ref.WeakReference<BA>(activityBA);
        anywheresoftware.b4a.objects.ViewWrapper.lastId = 0;
        _activity = new ActivityWrapper(activityBA, "activity");
        anywheresoftware.b4a.Msgbox.isDismissing = false;
        if (BA.isShellModeRuntimeCheck(processBA)) {
			if (isFirst)
				processBA.raiseEvent2(null, true, "SHELL", false);
			processBA.raiseEvent2(null, true, "CREATE", true, "b4a.example.main", processBA, activityBA, _activity, anywheresoftware.b4a.keywords.Common.Density, mostCurrent);
			_activity.reinitializeForShell(activityBA, "activity");
		}
        initializeProcessGlobals();		
        initializeGlobals();
        
        BA.LogInfo("** Activity (main) Create, isFirst = " + isFirst + " **");
        processBA.raiseEvent2(null, true, "activity_create", false, isFirst);
		isFirst = false;
		if (this != mostCurrent)
			return;
        processBA.setActivityPaused(false);
        BA.LogInfo("** Activity (main) Resume **");
        processBA.raiseEvent(null, "activity_resume");
        if (android.os.Build.VERSION.SDK_INT >= 11) {
			try {
				android.app.Activity.class.getMethod("invalidateOptionsMenu").invoke(this,(Object[]) null);
			} catch (Exception e) {
				e.printStackTrace();
			}
		}

	}
	public void addMenuItem(B4AMenuItem item) {
		if (menuItems == null)
			menuItems = new java.util.ArrayList<B4AMenuItem>();
		menuItems.add(item);
	}
	@Override
	public boolean onCreateOptionsMenu(android.view.Menu menu) {
		super.onCreateOptionsMenu(menu);
        try {
            if (processBA.subExists("activity_actionbarhomeclick")) {
                Class.forName("android.app.ActionBar").getMethod("setHomeButtonEnabled", boolean.class).invoke(
                    getClass().getMethod("getActionBar").invoke(this), true);
            }
        } catch (Exception e) {
            e.printStackTrace();
        }
        if (processBA.runHook("oncreateoptionsmenu", this, new Object[] {menu}))
            return true;
		if (menuItems == null)
			return false;
		for (B4AMenuItem bmi : menuItems) {
			android.view.MenuItem mi = menu.add(bmi.title);
			if (bmi.drawable != null)
				mi.setIcon(bmi.drawable);
            if (android.os.Build.VERSION.SDK_INT >= 11) {
				try {
                    if (bmi.addToBar) {
				        android.view.MenuItem.class.getMethod("setShowAsAction", int.class).invoke(mi, 1);
                    }
				} catch (Exception e) {
					e.printStackTrace();
				}
			}
			mi.setOnMenuItemClickListener(new B4AMenuItemsClickListener(bmi.eventName.toLowerCase(BA.cul)));
		}
        
		return true;
	}   
 @Override
 public boolean onOptionsItemSelected(android.view.MenuItem item) {
    if (item.getItemId() == 16908332) {
        processBA.raiseEvent(null, "activity_actionbarhomeclick");
        return true;
    }
    else
        return super.onOptionsItemSelected(item); 
}
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

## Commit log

2016-09-18 Uppdaterat Readme
    Uppdaterat readmefil med mina ändringar och länkar till de källor jag
    använt.
2016-09-25 Status på individuella AHE.
    Du ser status och loggar de olika AHE-enheterna. Du har alltså kolla på
    vilken du är ansluten till eller om du tappar anslutning till någon av
    de synkade enheterna.
2016-09-29 Mellanupload
    Inget spec, bara synd
    [Adafruit MAX4466 Mic Amp.brd, Adafruit MAX4466 Mic Amp.sch, FT232R-Breakout_v37.brd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]
2016-10-04 Update 4 okt
    Kicad och folder changes
    [AHE.brd, AHE.sch, AHE2.brd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]
2016-10-08 Inför träff
    Alla ändringar inför träff
    [Core1.sch, _saved_Core1.sch]
2016-10-15 Ljudet fungerar!
    Ljud fungerar-
    [Core1-B.Cu.gbr, Core1-B.Mask.gbr, Core1-B.SilkS.gbr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]
2016-10-16 Uppdaterat 3dmodel
    Uppdaterat 3dmodel
    [AHE.brd, AHE.sch, AHE2.brd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]
2016-10-17 PCB klar
    PCB Klar, vb moduler klara, 3d ritning uppdaterad.
    [Core1-B.Cu.gbl, Core1-B.Mask.gbr, Core1-B.Mask.gbs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]
2016-10-18 Fräsch commit
    3dmodel och rätt kod
    [Pyramid.skp]
2016-10-18 Model uppdaterad
    Michål och usbhål samt "balja" till kretskort
    [Pyramid.skp, kretskort.skp]
2016-10-20 PCB arbete och bilder
    Fortsätter PCB, ny två paneler. Lite nya bilder tagna på arbetet.
    [dev3.kicad_pcb]
2016-10-20 Uppdaterad FindSlot och Sync fungerar
    Sync funkar nu med timer. Ska flyttas över till Whileloop?
    FindSlot & SyncNew fungerar. Ska flyttas till modul?
    [Pyramid.skp]
2016-10-21 UDPModul - Logfunktion
    UDPModul - Logfunktion
    [dev3.kicad_pcb]
2016-11-01 UDPServer
    Hela UDP Server projecktet
    [Core1.kicad_pcb, Core1.sch, dev3.kicad_pcb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]
2016-11-08 Amplifier PCB
    [ampl_01-B.Cu.gbl, ampl_01-B.Mask.gbs, ampl_01-B.SilkS.gbo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]
2016-11-08 Mappändringar
    [Pyramid.skp, kretskort.skp]
2016-11-08 Volymkontroller och buggar
    Fungerande känslighetsinställningar för varje AHE.
    Buggfix: Synca samma enhet på samma slot om du tagit bort den precis.
    Smått ändrat utseende.
2016-11-16 0.2 update
    [Botten02.skp, Botten02.stl, Botten02Rep.stl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]
2016-11-16 Ny Pyramid
    Helt ny model.
    endast 8x8 i basen istället för 10x10. Lite lägre.
    Rätt mått på micingång, väggfäste samt USBingång.
    Annan infästning mellan lock och bas.
    Lite bredare "skål" för kretskortet.
    [Pyramid03.skp]
2016-11-17 Uppdaterat pyramid 0.3
    USBhålet bör fungera... bör...
    [Pyramid03.skp]
2016-11-20 Nästan färdig prototyp.-
    Du bör kolla om USBhålet stämmer. Måtten bör vara bra men du bör mäta så
    att positionen stämmer.
    [Pyramid03.skp]
2016-11-21 Nya fäste för lock/botten
    Ändrat till gammal variant
    [Pyramid03.skp]
2016-11-22 0.4 & 0.4.1
    Nya modeller uppe.
    [Pyramid 0.4.1.skp, Pyramid 0.4.skp, Pyramid03.skp]
2016-11-23 Pyramid04 3dprint format
    90kr/st
    [PyramidB.stl, PyramidBr.stl, PyramidT.stl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]
2016-11-25 Dev05 och Excel for alla nr
    [Serial numbers.ods]
2016-11-27 Pyramid0.5
    Ladduttaget är mätt på rätt sätt. Med hänsyn till marginaler. Har gjort
    en skalenlig 3dLaddare att testa med. SKA fungera!
    [Pyramid 0.5.skp]
2016-11-28 Dev10 PCB
    [dev10.kicad_pcb, dev10.sch]
2016-12-03 Ljuduppdatering
    Uppdatering av audio.
    [dev10.sch]
2016-12-04 Uppdatering av audiomodul
    Grymt mycket bättre ljud!
    [amplifier_02.kicad_pcb, amplifier_02.sch, dev10.kicad_pcb]
2016-12-08 Hårdvarustädning
    Städning mappar, USB Sticka ny!
    [AHE.brd, AHE.sch, AHE2.brd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]
2016-12-10 Start och stop av ljud funkar!!
    Nu fungerar det!
    Sista innan 1.0 är syncen i början. Hur får vi fram vilken IP mjukvaran
    ska synca till!?
    Även en färdig Pyramid syncad!
    [Pyramid 0.5.skp]
2016-12-14 Hårdvara
    [01dev.kicad_pcb, 01dev.sch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]
2016-12-18 Bandlås
    [bandlås-013Bsträng-rep.stl, bandlås-013Bsträng.stl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]
2016-12-18 USB Sticka 3D
    Dev 06 + 3d modell usb
    [01dev_long.kicad_pcb]
2016-12-31 Tagit bort onödiga saker
    [Bokföring.xls, Serial numbers.ods]
2017-01-01 Fungerande utan klick på gammal HW
    Ändrat källkod i UDPmodul och Augiomodul. Funkar utan klick på HW.
    [Pyramid 0.5.stl, Pyramid 0.6BUILD.stl, Pyramid 0.6BUILDrep.stl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]
2017-01-03 Lite Div
    [01dev_long_microUSB.kicad_pcb, 02dev.kicad_pcb, 02dev.sch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]
2017-01-08 Uppdateringar
    ClearSync, AndroidAPP och senaste 3dmodelen
    [BOTT06BUILD.stl, BOTT06BUILDrep.stl, TOP06BUILD.skp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]
2017-01-09 Firmware07 and Pics
    [02dev_long.kicad_pcb]
2017-01-10 Buggfixar i Android
    Fixat Sync vid start. Syncknappen, manuell sync. Notification och ikon.
    Tangentbordet försvinner vid "OK" på mansync.
    [main.java]
2017-01-30 New hardware
    [02dev.sch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]
2017-03-02 NewPCB Things
    [02devOPA345.sch, 02devOPAdual.sch, Nodes.xls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]

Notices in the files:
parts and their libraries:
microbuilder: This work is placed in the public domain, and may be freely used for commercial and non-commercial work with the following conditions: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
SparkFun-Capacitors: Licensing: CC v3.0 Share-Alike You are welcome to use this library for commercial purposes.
